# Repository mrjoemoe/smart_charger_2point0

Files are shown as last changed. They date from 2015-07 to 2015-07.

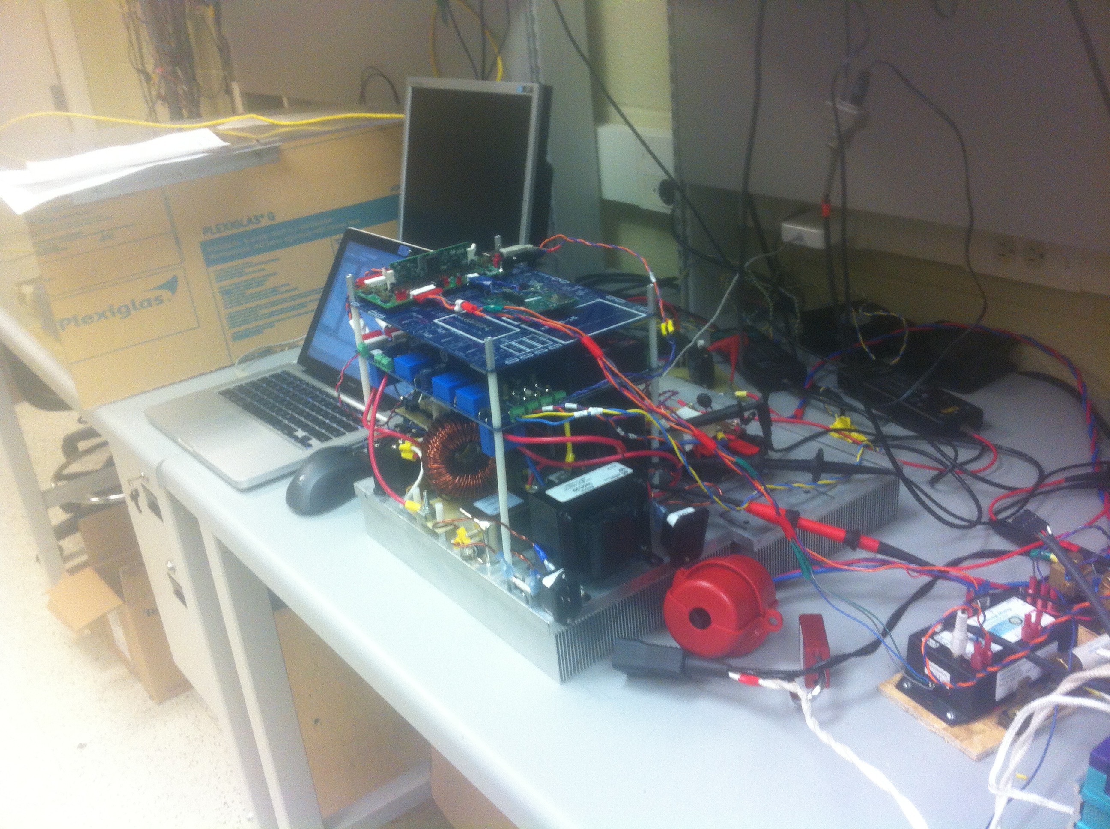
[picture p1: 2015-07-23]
smart_charger_pictures/IMG_2184.JPG

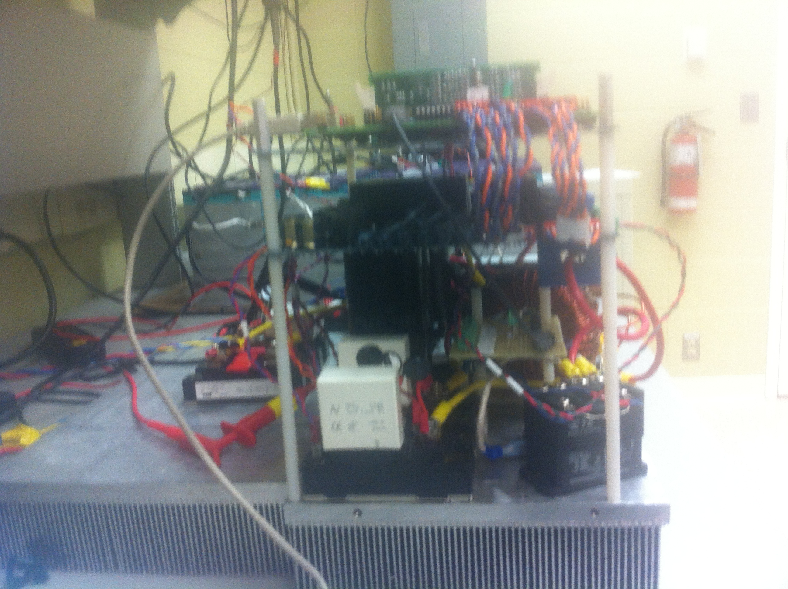
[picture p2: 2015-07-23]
smart_charger_pictures/IMG_2187.JPG

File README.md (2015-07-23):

# smart_charger_2point0
Project folder for the design of a level 1 bidirectional charger

For this project I designed a level 1 bidriectional EV charger capable of charging/discharging a 4kWh battery pack up to 20A @ 120VAC

Uploaded files include:
- firmware for the TMS320F2808 digital signal controller which was written in embedded C
- JS/HTML written for the Muratta SN8200 wifi controller (connected to TMS320F2808 through I2C) for wireless access
- altium files for pcb design
- matlab/simulink files used for controller development and design

My apologies for the poor organization

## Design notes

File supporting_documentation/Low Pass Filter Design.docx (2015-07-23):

Low Pass Filter Design

The digital low pass filter to be implemented in the lab was designed using traditional controller design techniques and state space methods. First a second order low pass filter is designed in the analog domain using traditional techniques. The damping ratio ( ζ) and cutoff frequency ( w_o^2 ) are chosen to be 0.707 and 400π respectively.

G(s)= (w_o^2)/(s^2 +2ζw_o s+ w_o^2)

With these component values chosen it can be seen in Figure 1 that this controller is very stable with both poles far into the open left hand plane and no zeros. However from Figure 2 it can be seen that there is approximately a 53.2O phase lag between the input and output signal and a gain of -0.56 dB. In the lab is it required that the input and output signals are in phase with unity gain. Therefore it is required to design a third order controller.

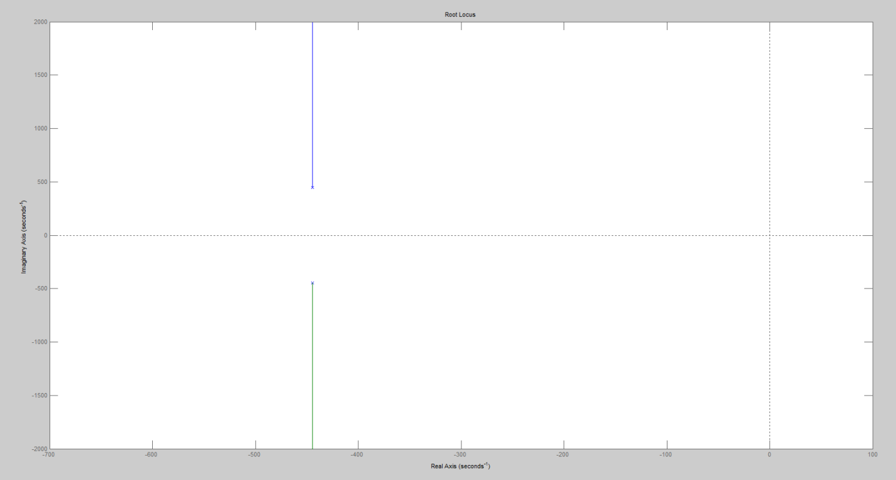
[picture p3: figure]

Figure 1. Low Pass Filter Root Locus Plot (Analog)

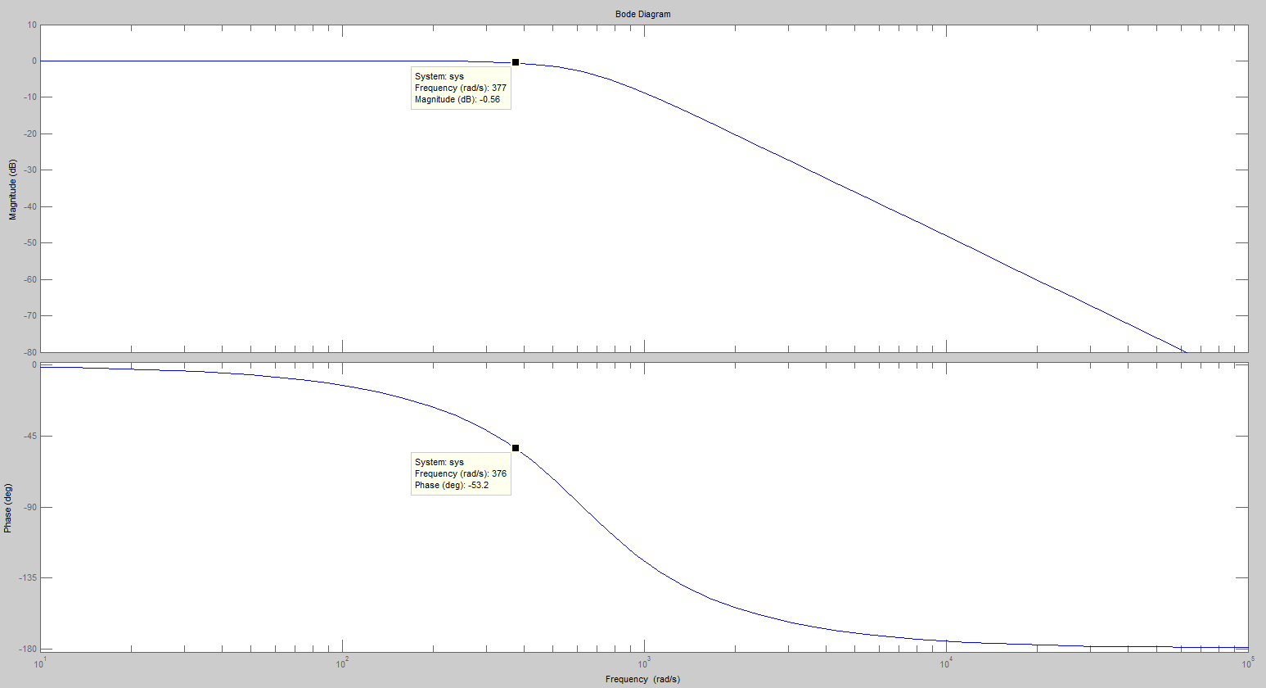
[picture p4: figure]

Figure 2. Low Pass Filter Bode Plot (Analog)

The controller will be augmented to with a lead compensator so that the controller takes on the form

G(s)= K/(√a)((1+aTs)/(1+Ts))((w_o^2)/(s^2 +2ζw_o s+ w_o^2))

where

a= (1+sin∅_m)/(1-sin∅_m)

T= 1/(w_m √a)

The controller will be filtering data at 60 Hz so by setting w_m =120π , ∅_m =53. 2O and selecting K such that unity gain is achieved we get a response as shown in Figure 3 and Figure 4. Now we have a stable low pass filter with a cutoff frequency of 200 Hz that provides unity gain and no phase shift at 60 Hz.

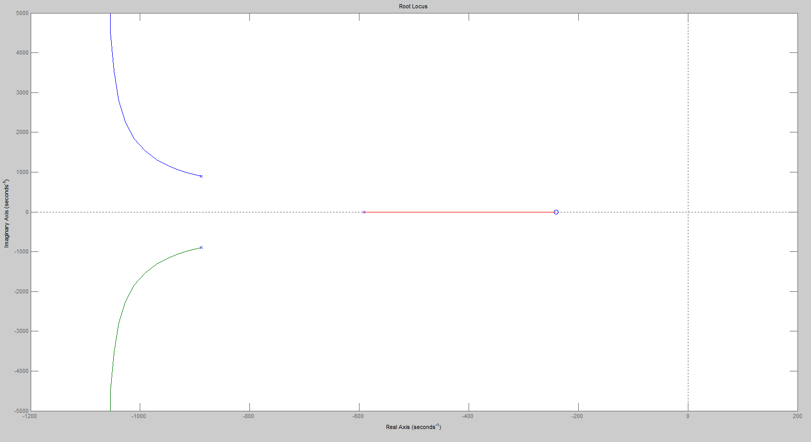
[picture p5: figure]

Figure 3. Third Order Low Pass Filter, root locus, Analog

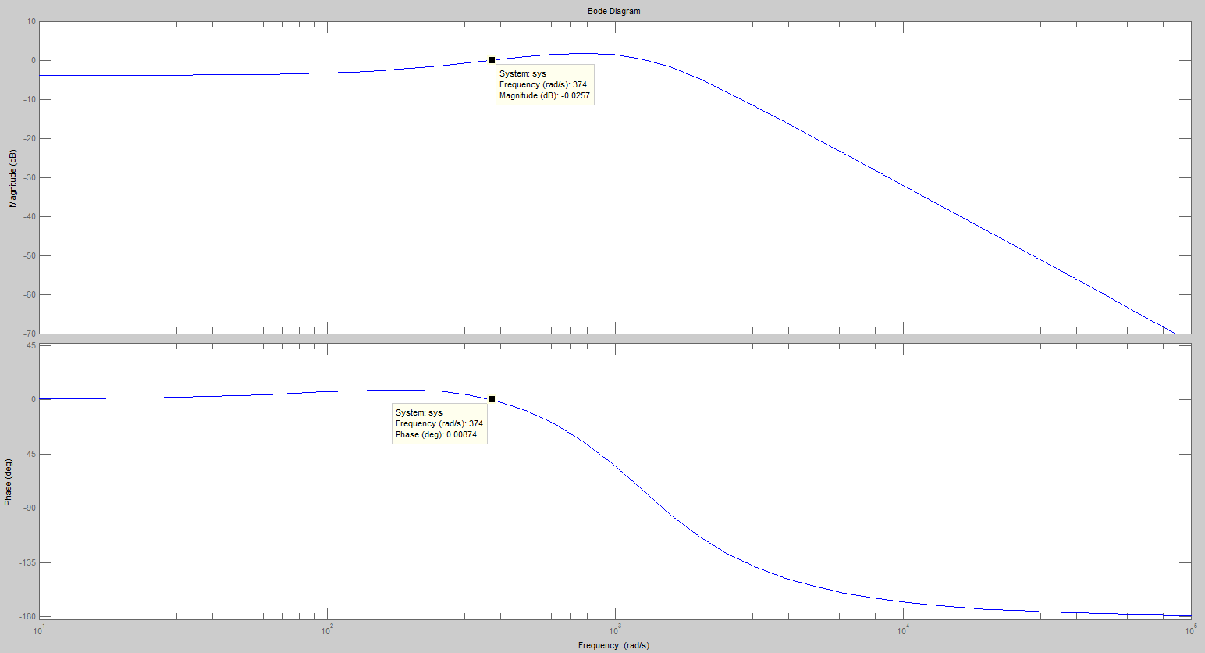
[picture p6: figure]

Figure 4. Third Order Low Pass Filter, bode plot, analog

The next step is to convert the filter to a discrete model that can be implemented with a microcontroller. Using the tools provided in matlab the following script was written to quickly calculate the third order filter parameter values.

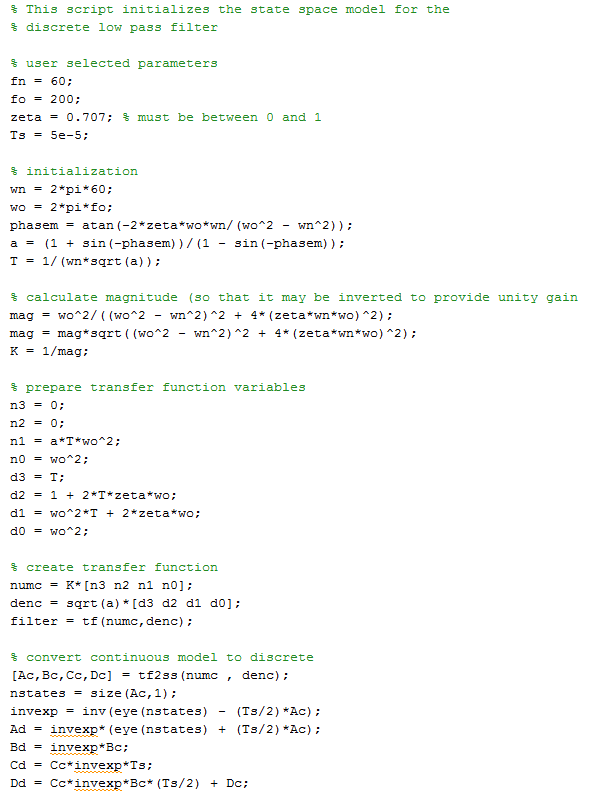
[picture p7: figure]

Once the transfer function is designed it is converted to a state space model using the tf2ss() function. Then the continuous state space model is converted to a discrete state space model using the following conversions:

A_d =(I-(T_s)/2A_c )^(-1) (I+(T_s)/2A_c )

B_d =(I-(T_s)/2A_c )^(-1) B_c

C_d =C_c (I-(T_s)/2A_c )^(-1) T_s

D_d =C_c (I-(T_s)/2A_c )^(-1) B_c ((T_s)/2)+D_c

This results in the following discrete state space parameters:

A_d =[0.8852, -125.0779, -4.4036E-34.7131E-3, 0.9969, -1.10091.1783E-9, 4.9922E-5, 1.0000]

B_d =[0.94262.3566E-55.8914E-10]

C_d =[0.0029, 124.9691, 2.9817E-4]

D_d =[0.0015]

Based on these parameters the output of the filter y[n] can be calculated based on the input u[n] at each sampled period of 50 µs according to the state space relationship below.

x[n+1]=A_d x[n]+ B_d u[n]

y[n]=C_d x[n]+ D_d u[n]

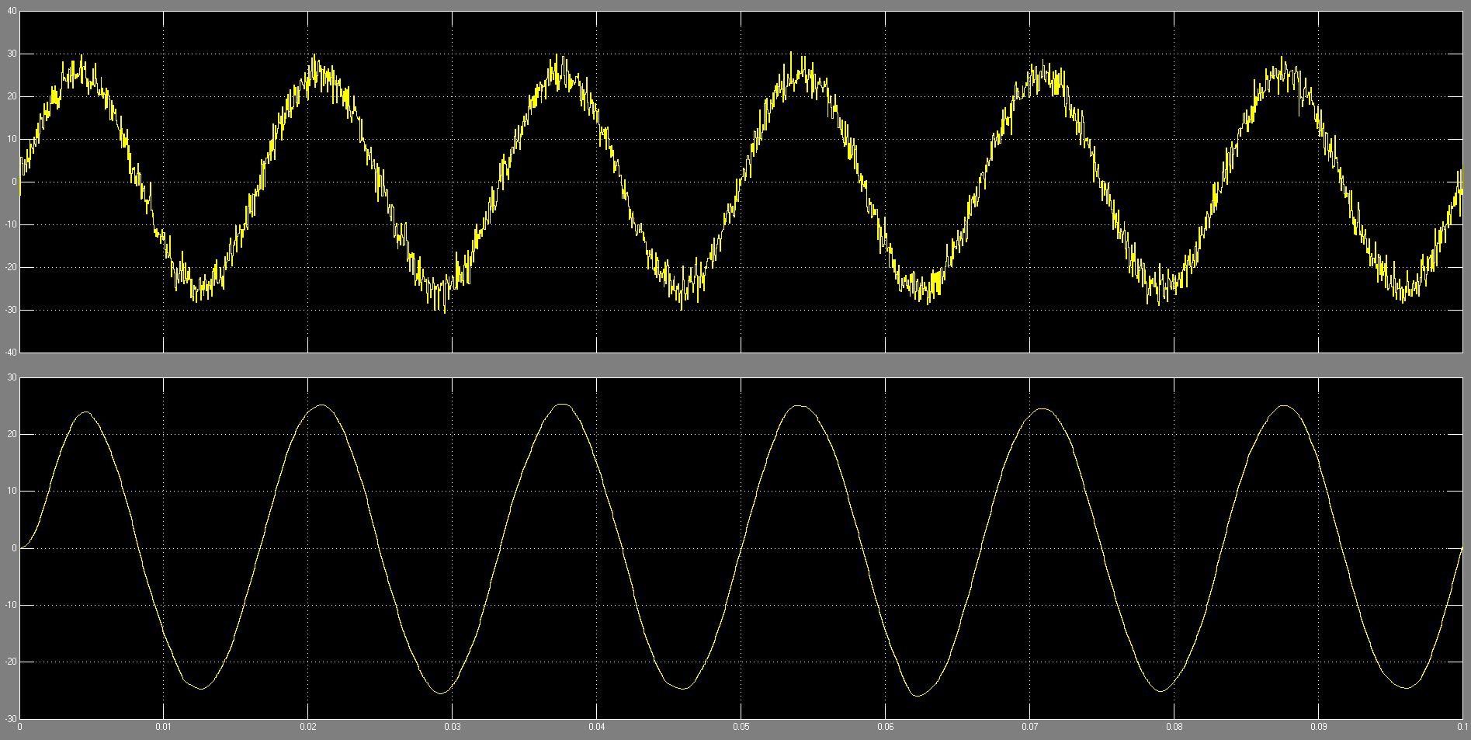
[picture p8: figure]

Figure 5. Sample of Digital Filter

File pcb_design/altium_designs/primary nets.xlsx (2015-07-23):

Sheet: nets
Primary Nets | Desciption
+15V | +15V supply for voltage and current sensors
-15V | -15V supply for voltage and current sensors
GND1 | GND supply for voltage sensors, current sensors and fiber optic transmitters
GND2 | GDN supply for fiber optic receivers
5V1 | 5V supply for opamps in voltage and current sensors
5V2 | 5V supply in fiber optic receivers
15V2 | 15V supply for igbt gate drivers
IGBT1 | igbt 1 emitter voltage
IGBT2 | igbt 2 emitter voltage
IGBT3 | igbt 3 emitter voltage
IGBT4 | igbt 4 emitter voltage
IGBT5 | igbt 5 emitter voltage
IGBT6 | igbt 6 emitter voltage

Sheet: sheet names
sheet | code
gate_drive_array | G
fo_tx_array | T

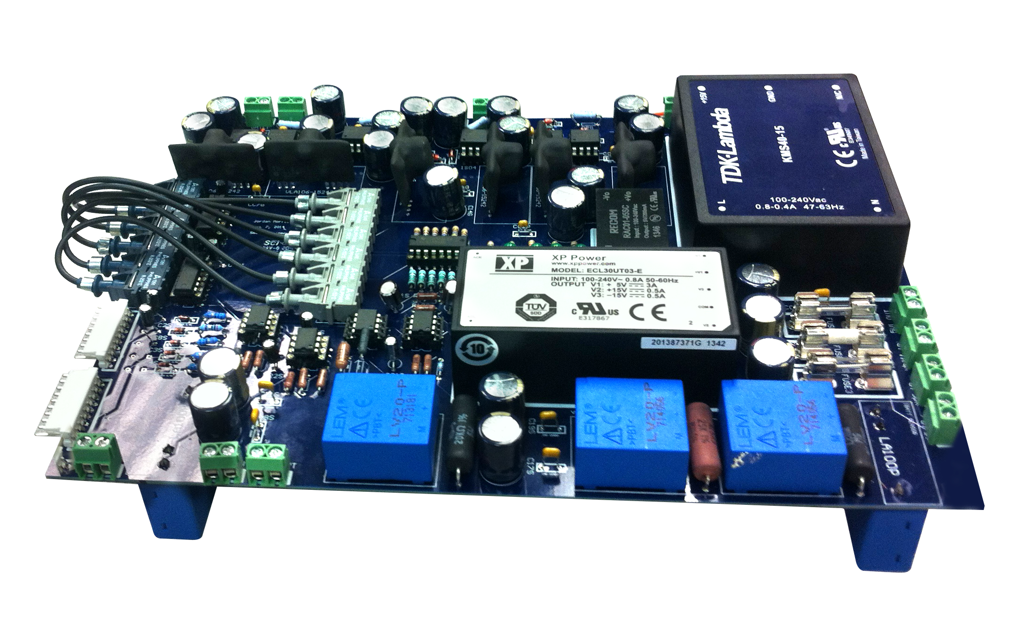
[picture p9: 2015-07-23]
smart_charger_pictures/pcba_final.png

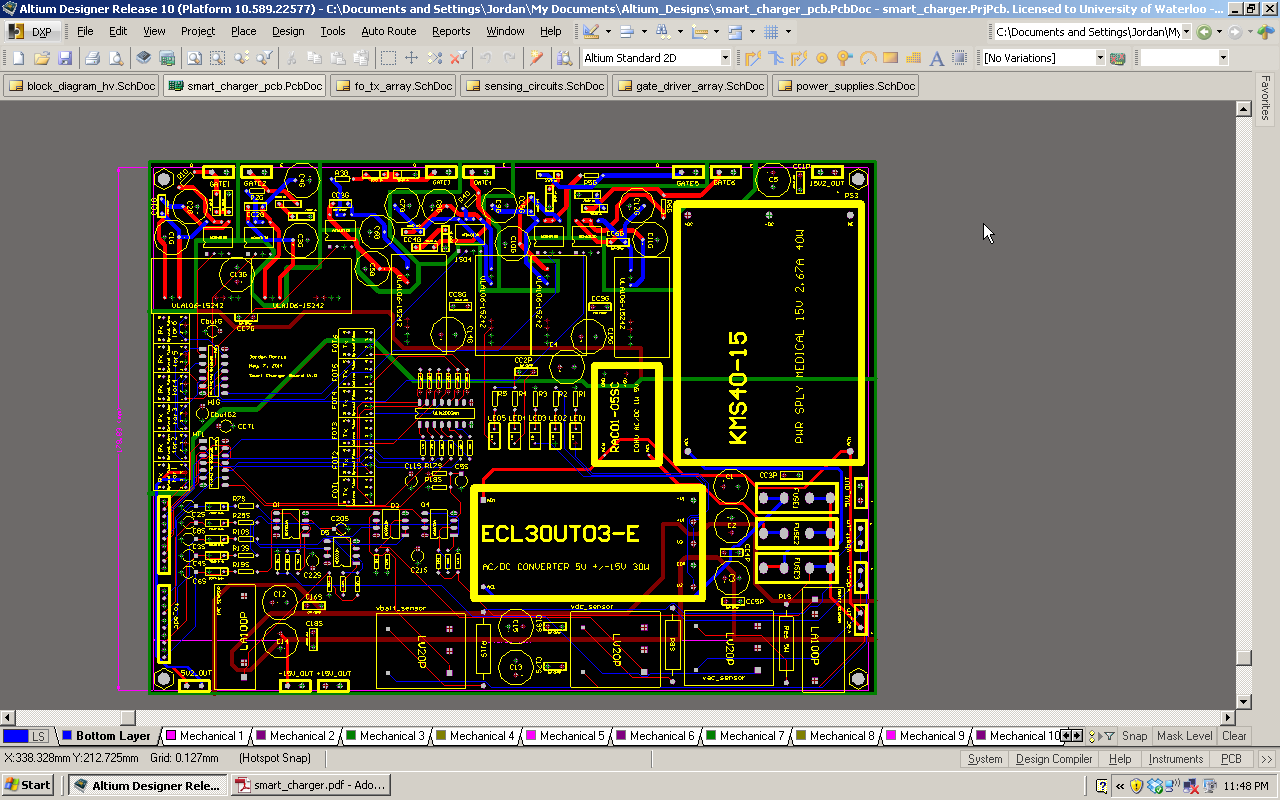
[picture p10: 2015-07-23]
smart_charger_pictures/pcb.bmp

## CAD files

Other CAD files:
tms320f2808_firmware/Debug_RAM/mainxs.obj
tms320f2808_firmware/Debug_RAM/main (Jordans MacBook.lan's conflicted copy 2013-12-22).obj
tms320f2808_firmware/Flash/main.obj
tms320f2808_firmware/Debug_RAM/mainfeedforward.obj
tms320f2808_firmware/Debug_RAM/maindouble.obj
tms320f2808_firmware/Debug_RAM/mainfeedbackzero.obj
tms320f2808_firmware/Debug_RAM/mainopenloop.obj
tms320f2808_firmware/Debug_RAM/main.obj
tms320f2808_firmware/Debug_RAM/mainfeedforward20091221.obj
tms320f2808_firmware/Debug_RAM/mainclosedloop_P_20091208.obj
tms320f2808_firmware/Flash/DSP280x_CodeStartBranch.obj
tms320f2808_firmware/Debug_RAM/DSP280x_CodeStartBranch.obj
tms320f2808_firmware/Flash/INVERTER_control.obj
tms320f2808_firmware/Debug_RAM/overload.obj
tms320f2808_firmware/Debug_RAM/INVERTER_control.obj

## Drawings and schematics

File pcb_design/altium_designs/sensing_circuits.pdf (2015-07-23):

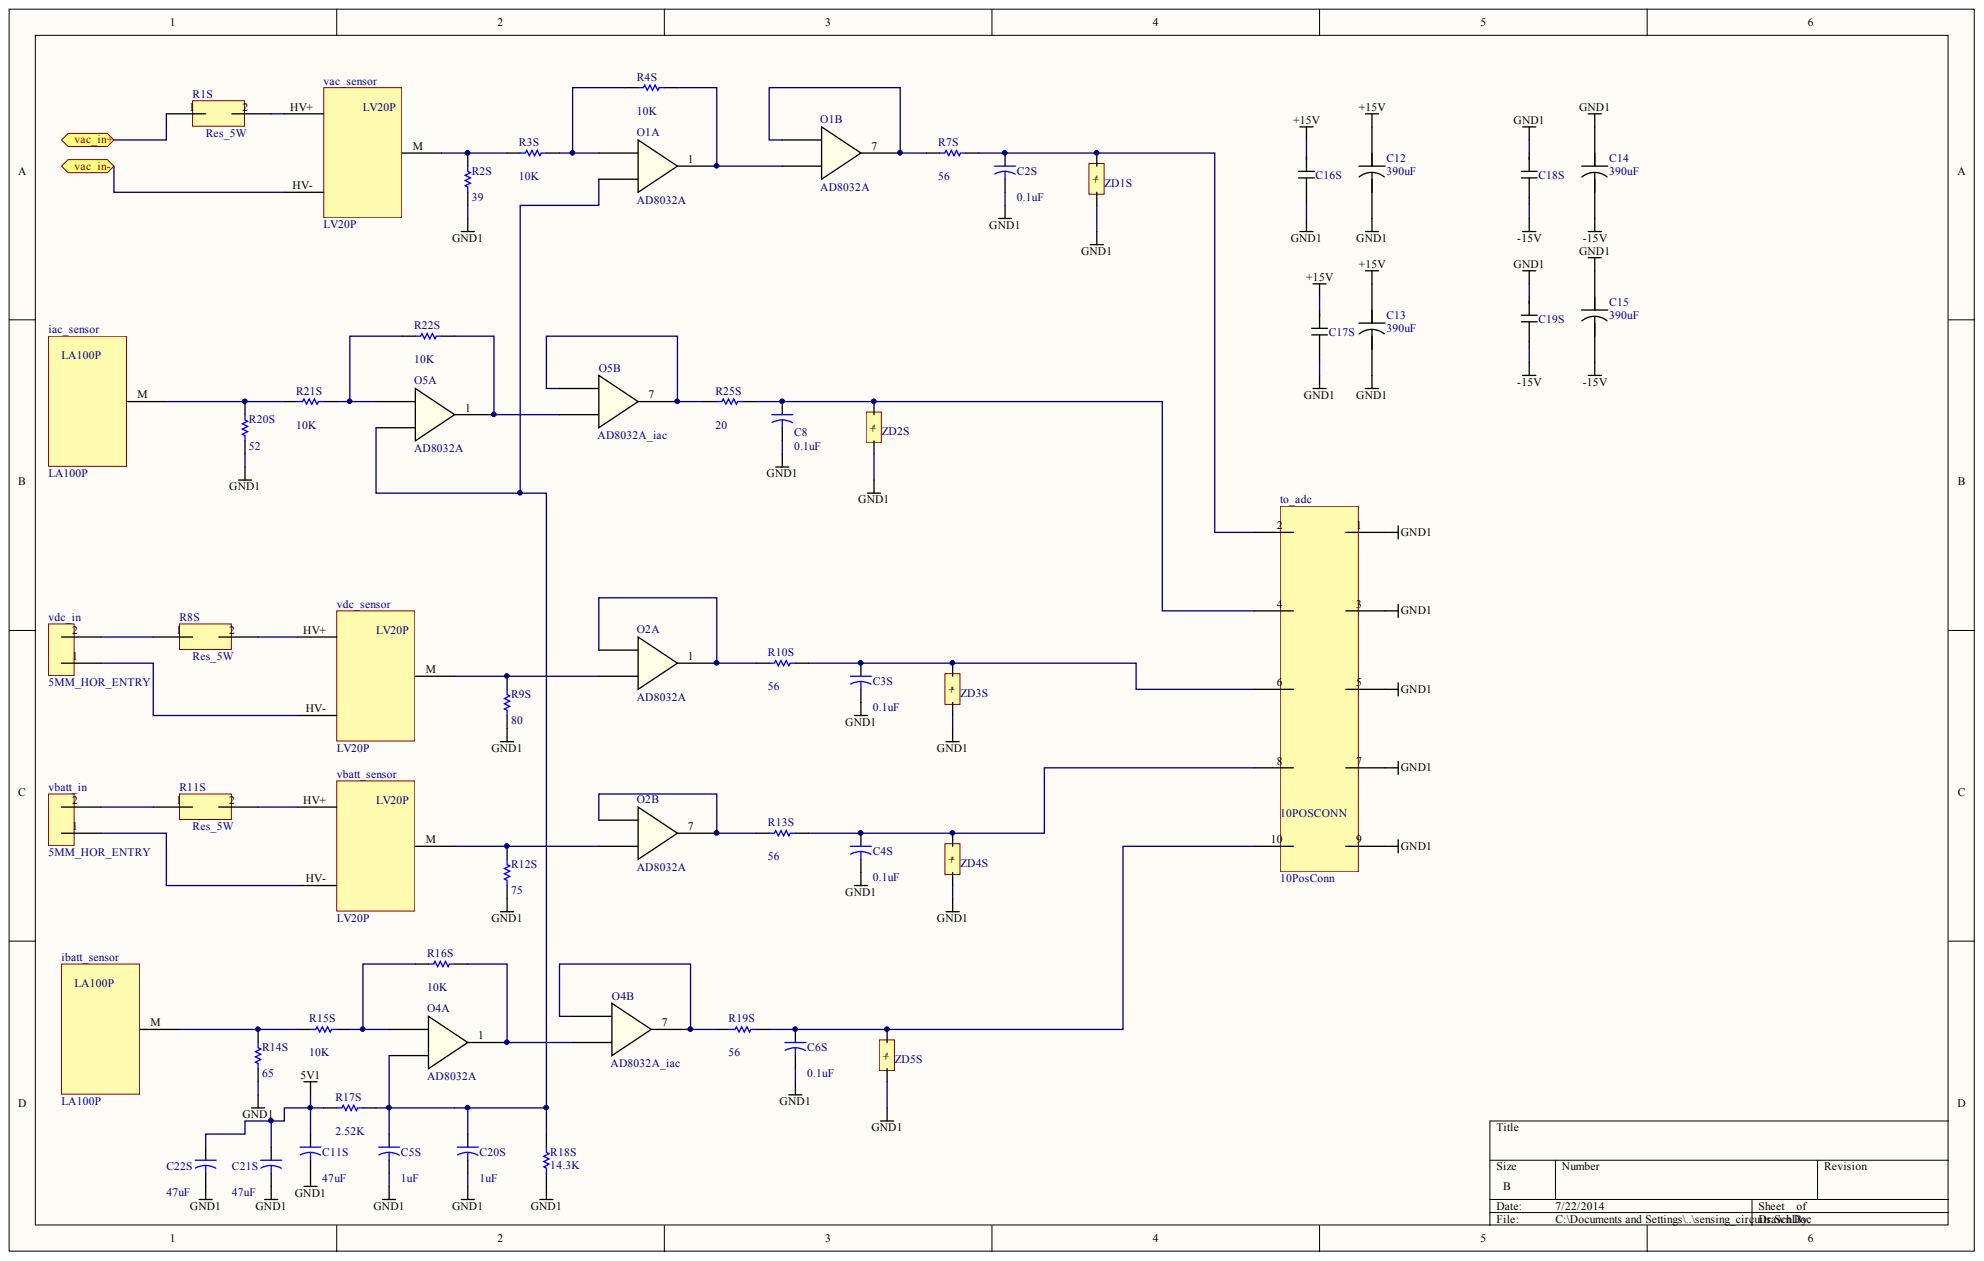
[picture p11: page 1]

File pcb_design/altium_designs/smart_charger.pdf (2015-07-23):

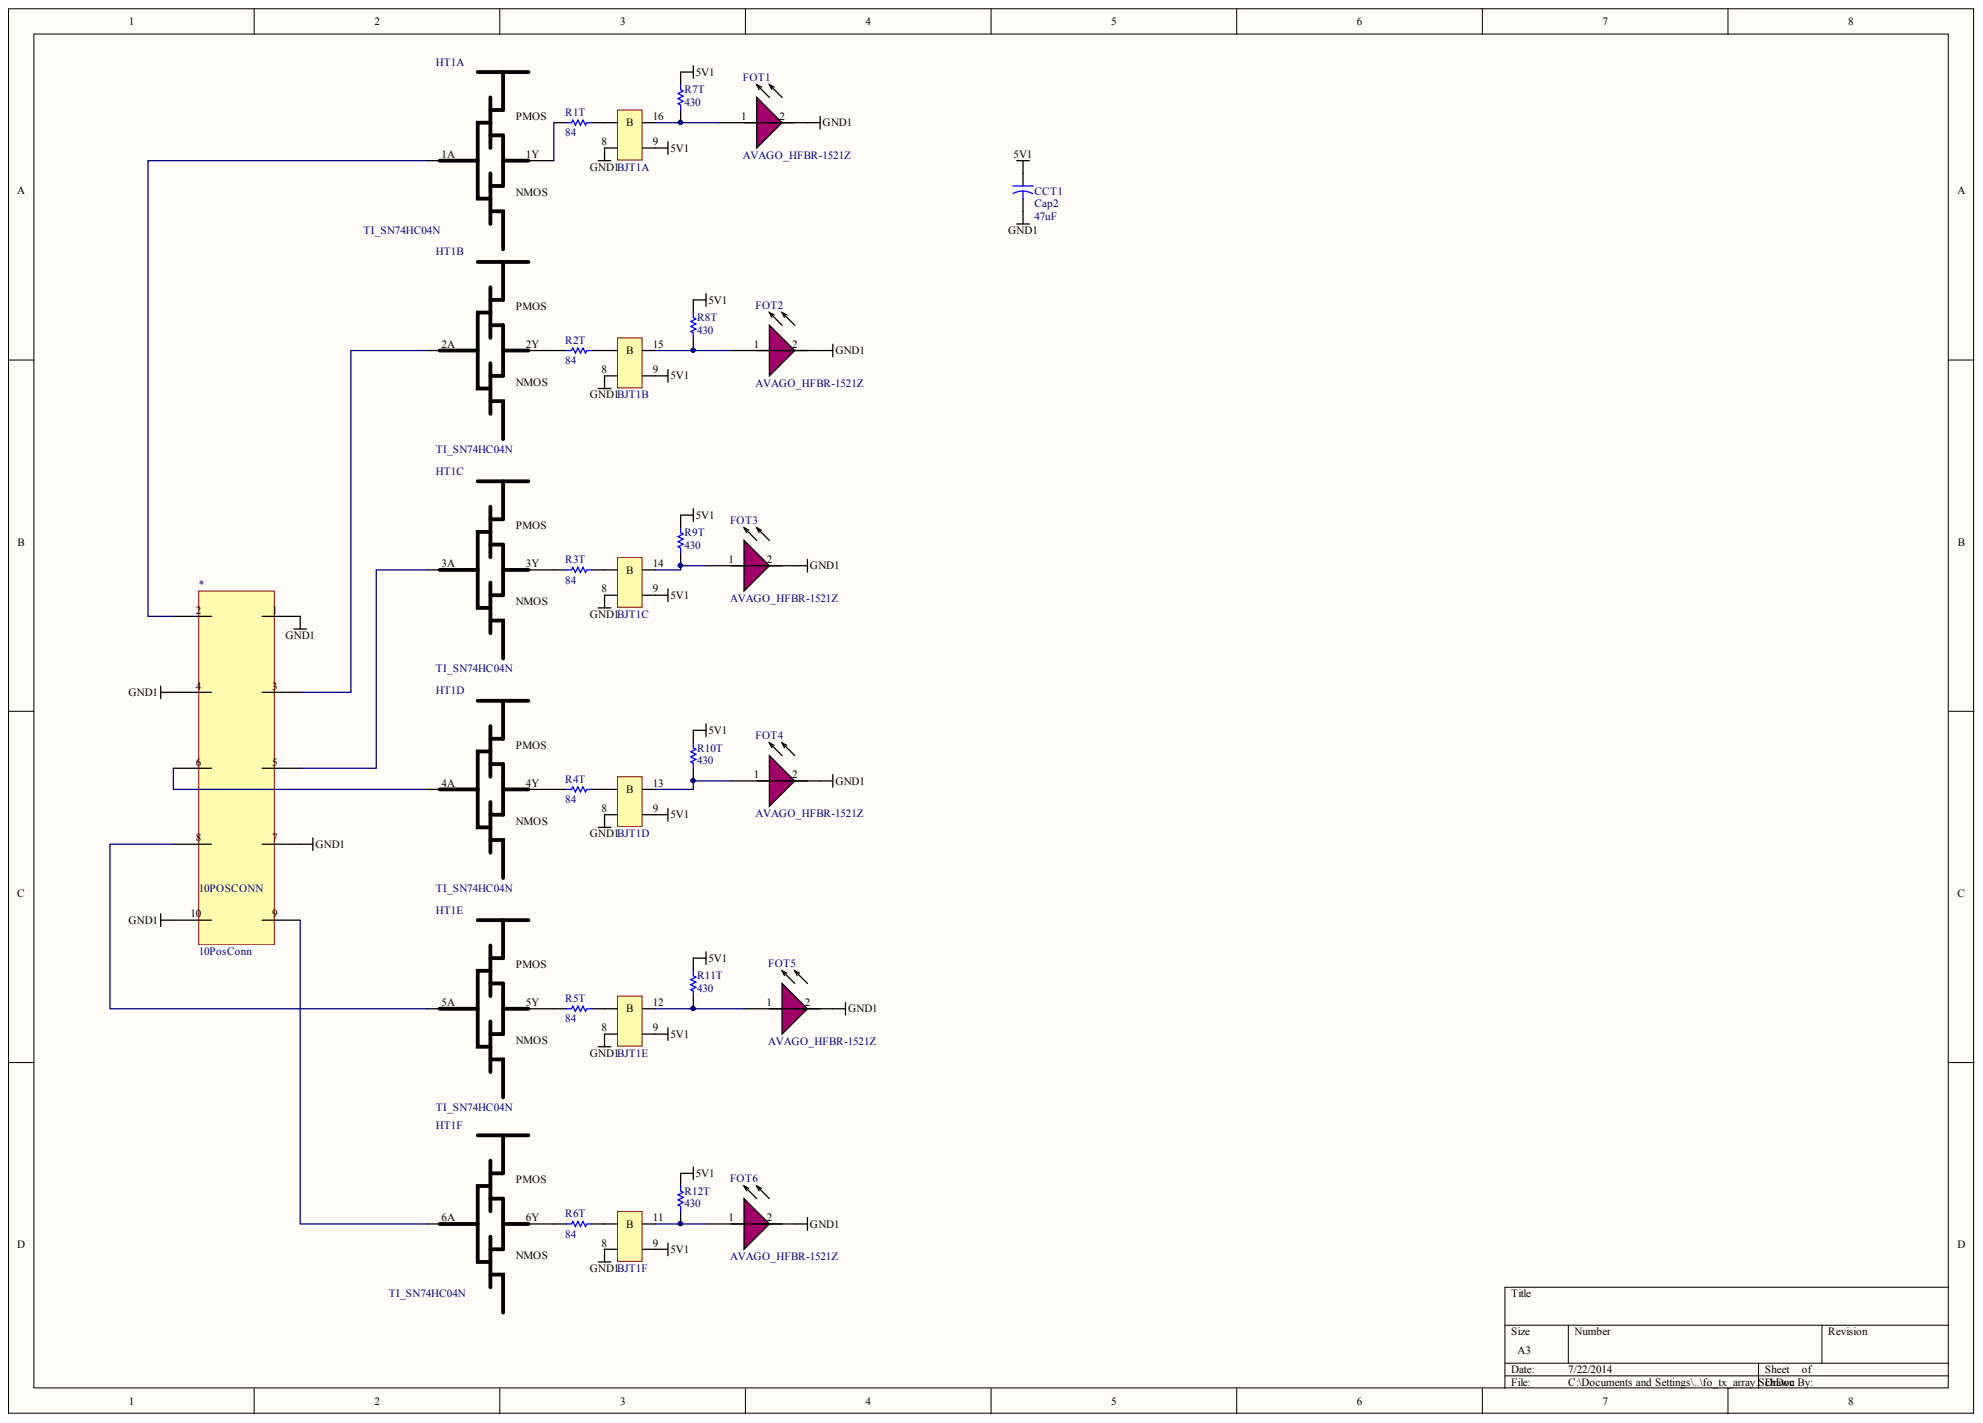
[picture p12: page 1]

10POSCONN | 9

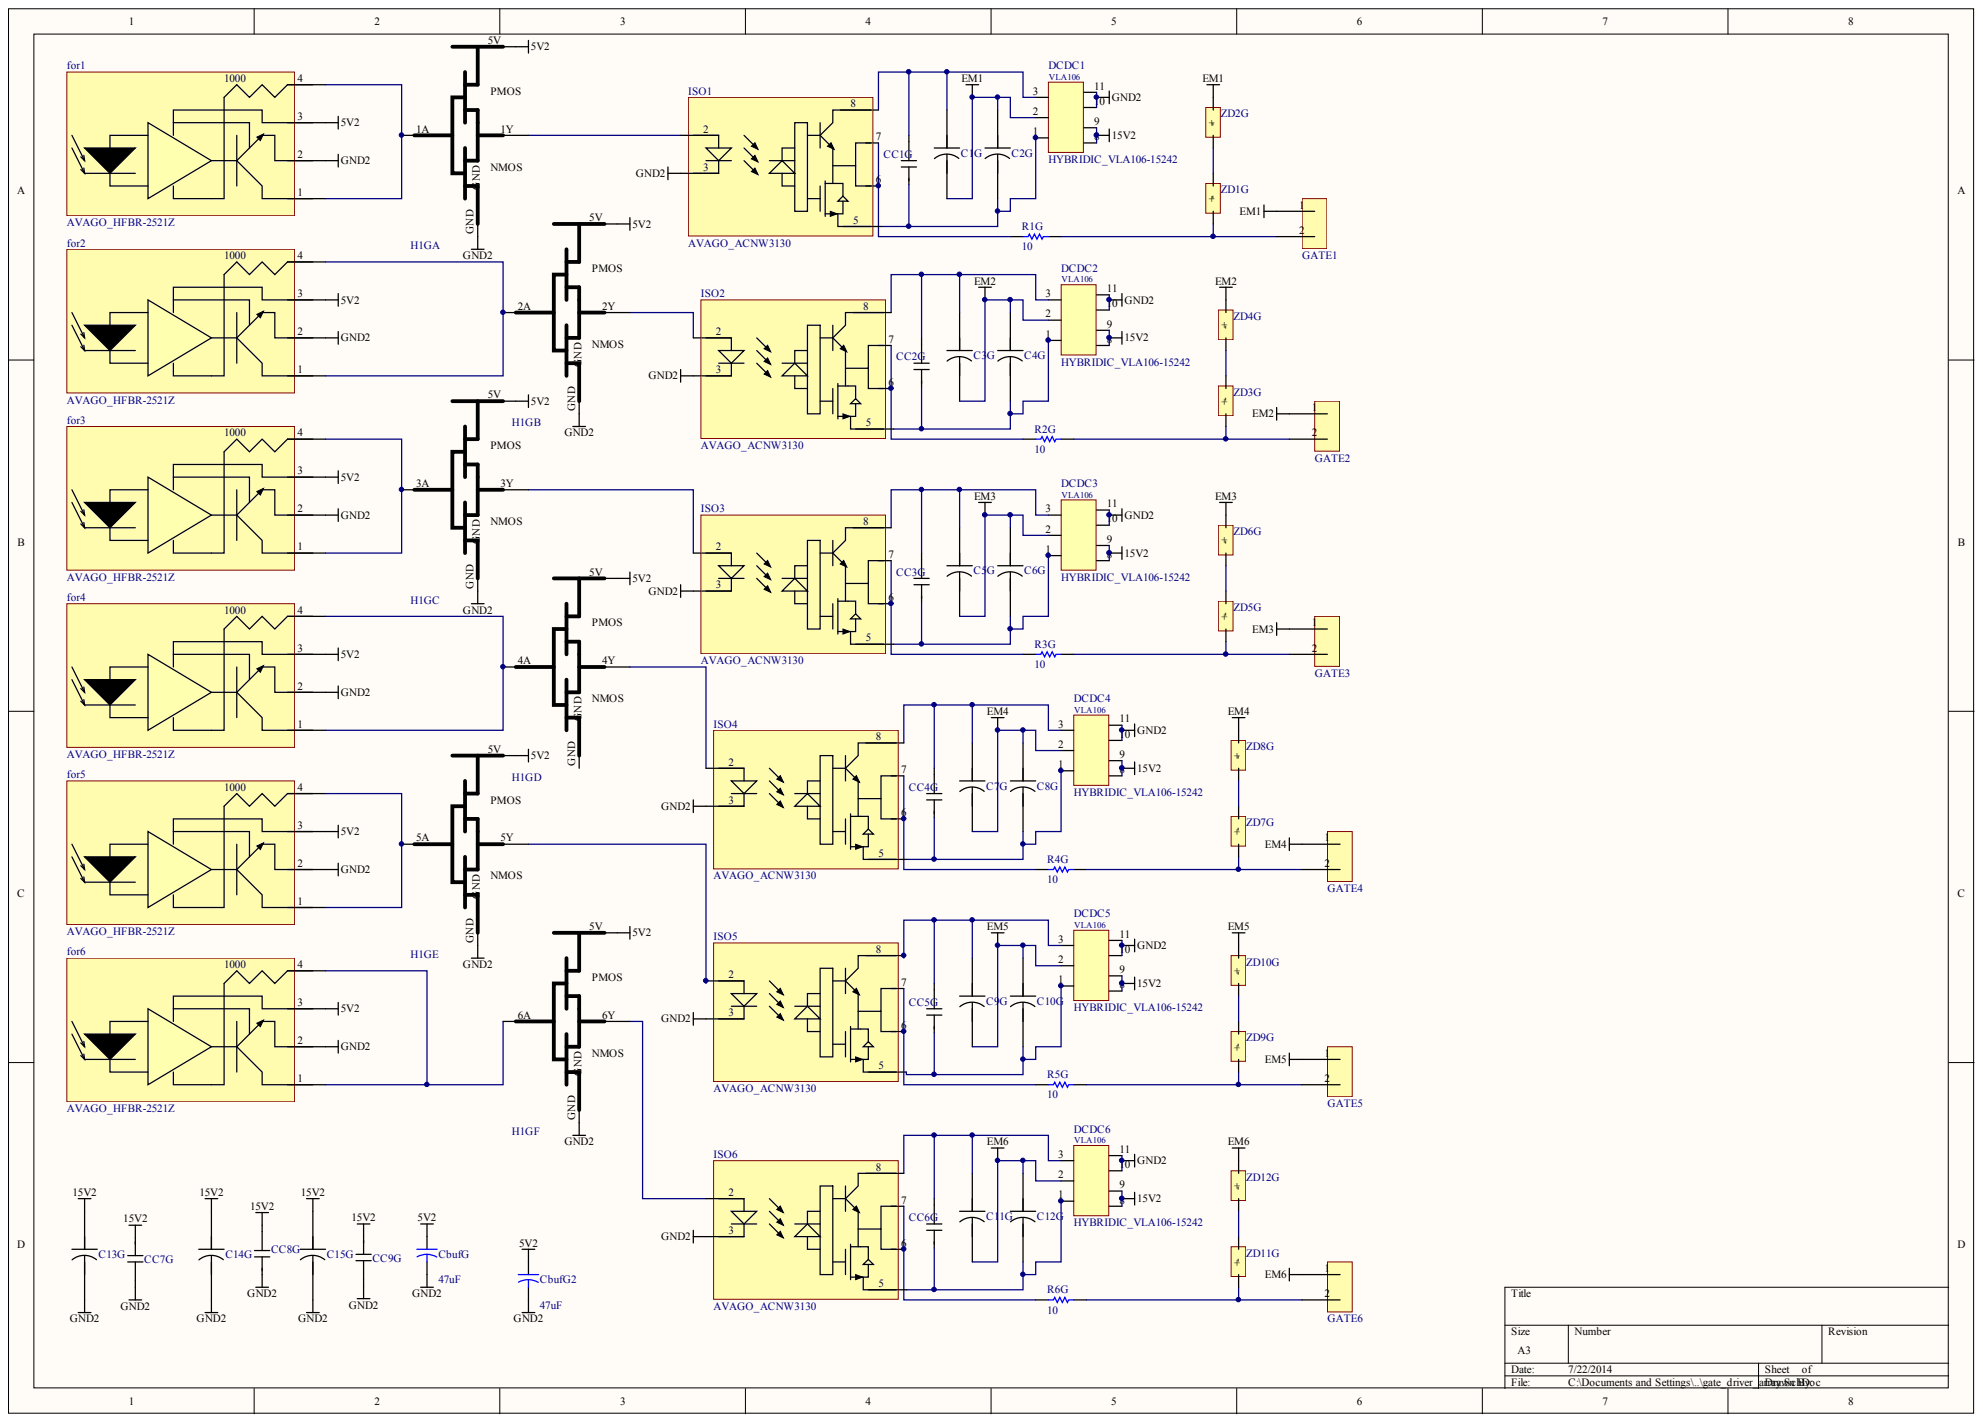
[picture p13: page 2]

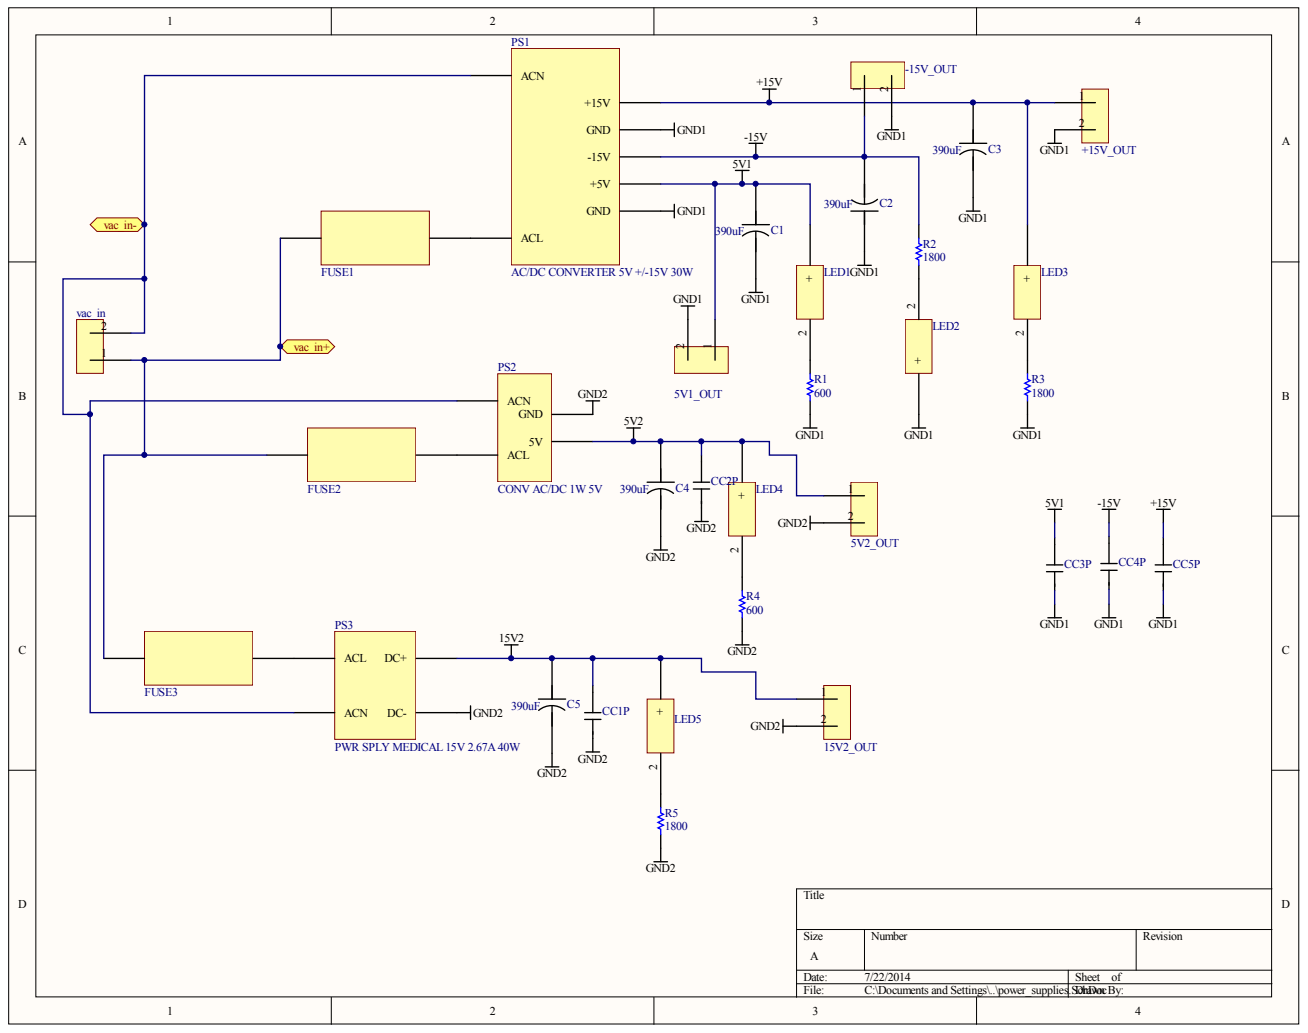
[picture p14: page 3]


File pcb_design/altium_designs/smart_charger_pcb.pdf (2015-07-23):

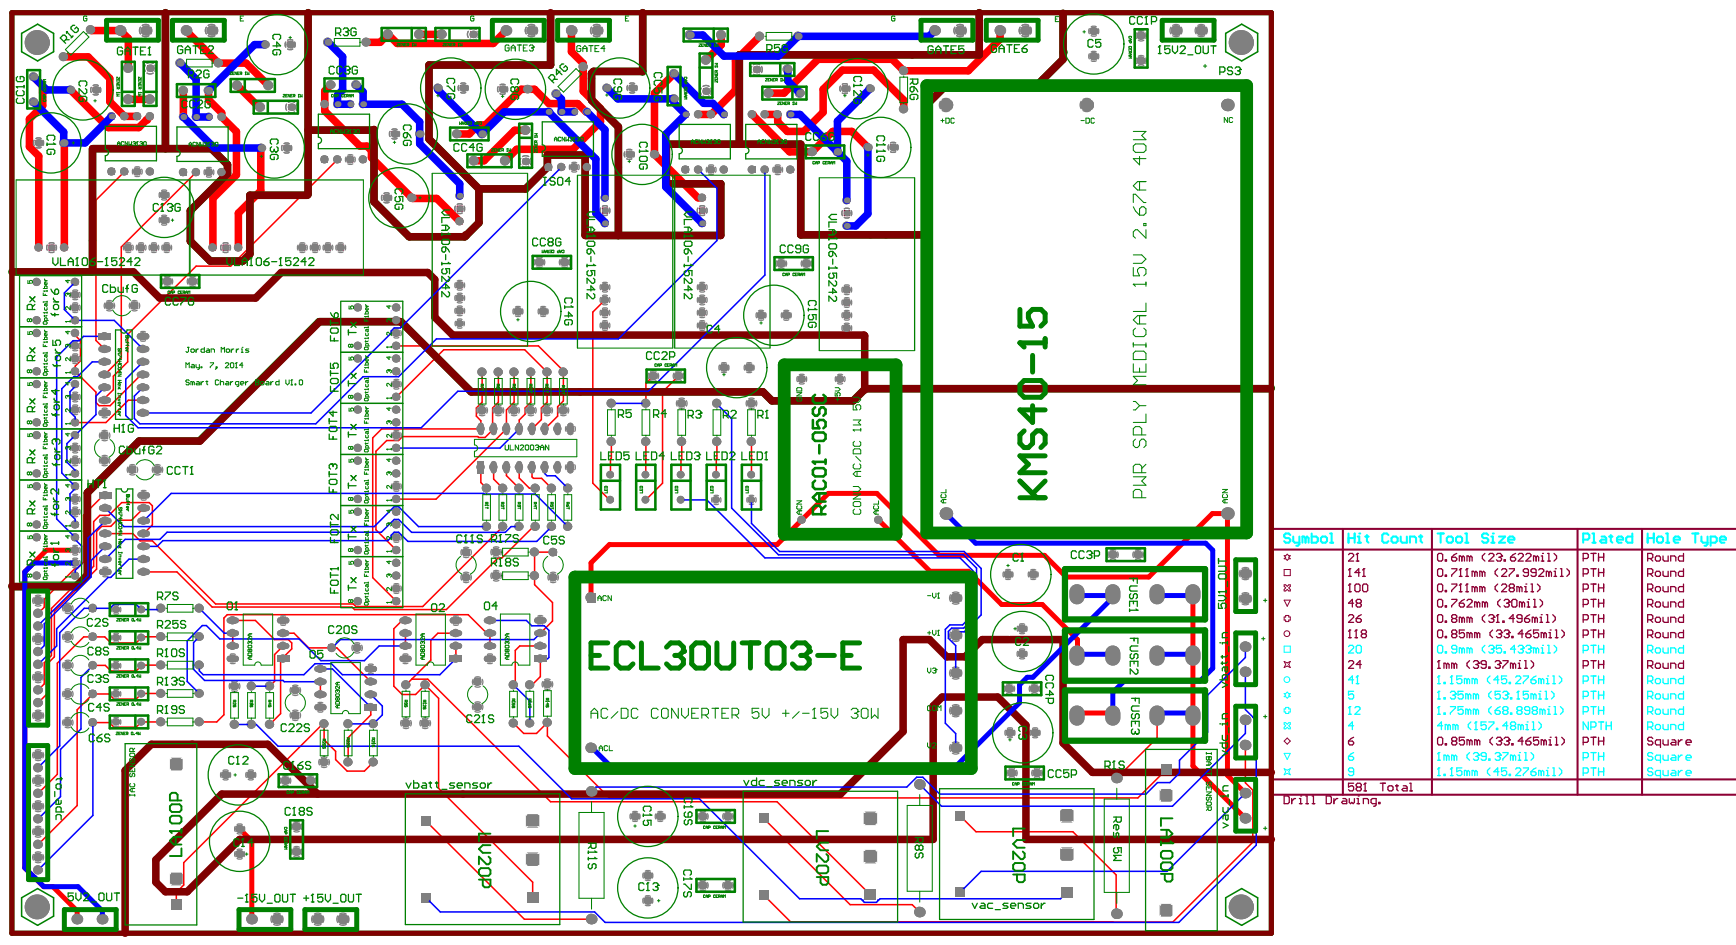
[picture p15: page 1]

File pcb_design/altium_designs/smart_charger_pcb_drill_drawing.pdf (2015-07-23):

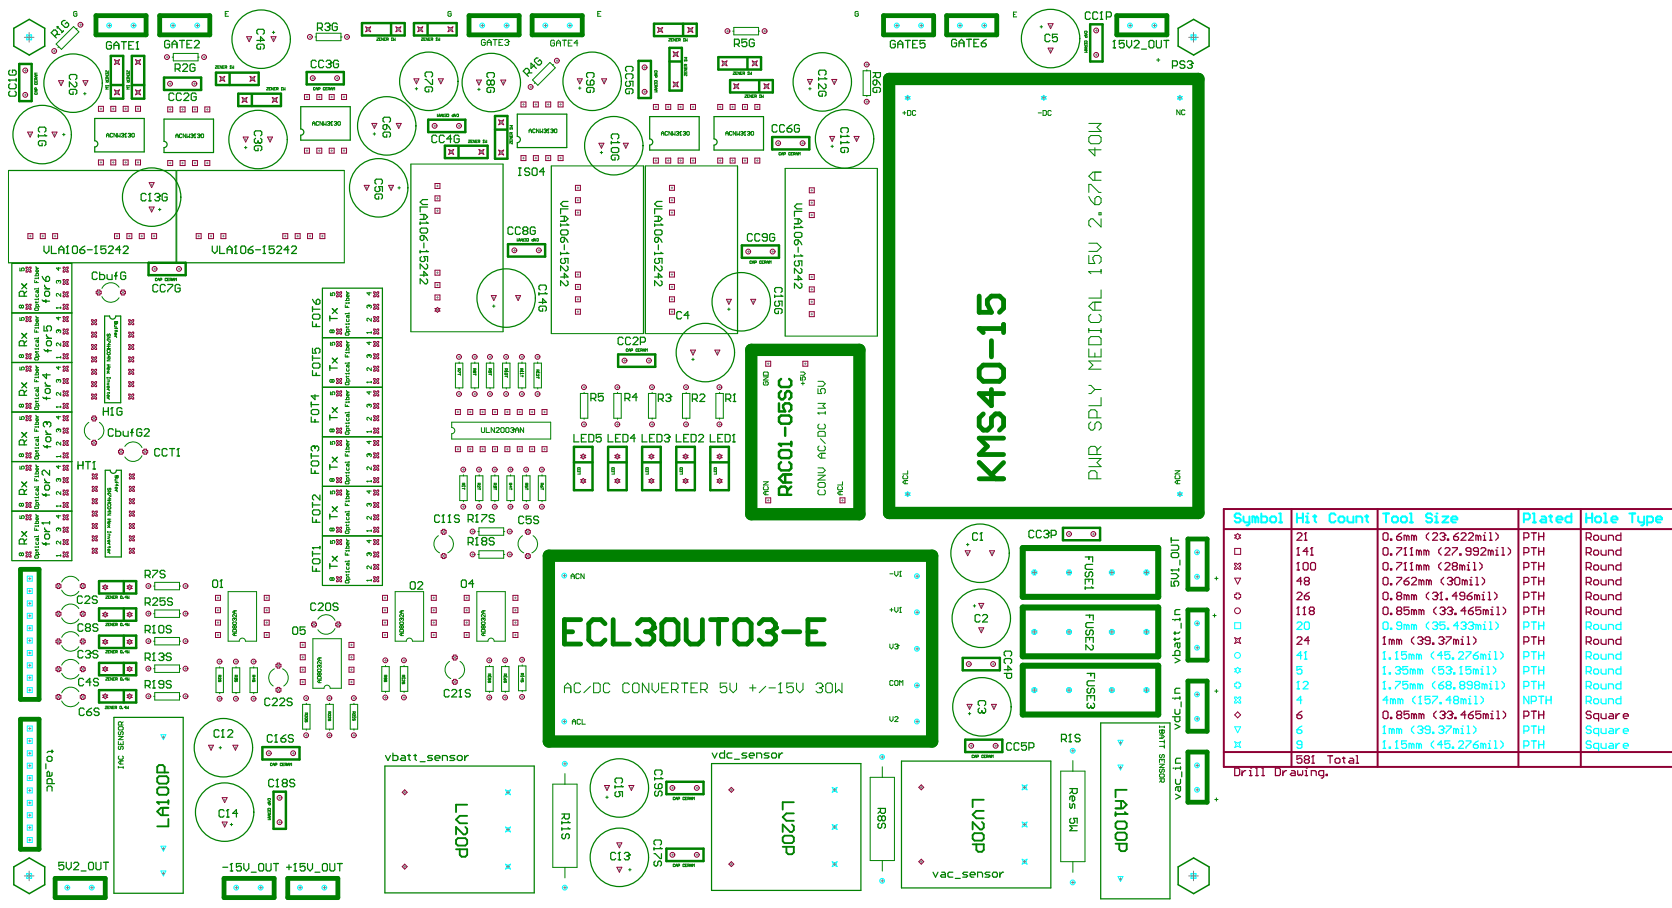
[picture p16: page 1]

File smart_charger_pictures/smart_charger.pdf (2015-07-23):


10POSCONN | 9




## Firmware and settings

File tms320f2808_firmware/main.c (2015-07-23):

// AC/DC Converter
// Jordan Morris
// Nov. 7, 2013

// START

// Table of Contents

//  S0.1 	System Header Files Declarations

//  S1.1 	Function Defintions
//  S1.2 	Main Function
//  S1.2.1 	PLL,WatchDog,Clocks initialization
//  S1.2.2 	PIE initialization
//  S1.2.3 	Set GPIO as EPWM
//	S1.2.4 	Set GPIO as LEDS and switches
//	S1.2.5 	FLASH initialization
//	S1.2.6 	ePWM synchronization
//	S1.2.7 	ePWM initilization
//	S1.2.8 	ADC initialization
//	S1.2.9 	Interrupt Initilization Section

//	S2.0 	Main Control Run
//	S2.1 	PI Controller Algorithm
//	S2.2 	DQ Controller Algorithm
//  S2.3 	enable acdc igbts
//  S2.4 	protection function
//  S2.5 	ADC sampler function
//	S2.6 	ac dc gate driver function
//  S2.7 	RMS calculation
//  S2.8 	digital filter function
//  S2.9 	Proportional-Integral Block
//  S2.10 	Vd Correction Factor 
//  S2.11 	Vq correction Factor
//  S2.12 	Id correction factor
//	S2.13 	Iq correction factor
//	S2.14 	Vab-dq Transform
//  S2.15 	Iab-dq transform
//  S2.16 	Power Calculations
//	S2.17 	AC/DC reverse power flow
//	S2.18 	DC/DC gate drivers
//	S2.19 	Constant Voltage Charging Mode
//	S2.20 	Constant Current Charging Mode
//  S2.21 	Active Power Controller
//  S2.22 	Reactive Power Controller
// 	S2.23 	Mode Select
// 	S2.24 	DC/DC igbts ON
// 	S2.25 	DC/DC igbts OFF
//	S2.26	AC/DC variable reset
// 	S2.27	DC/DC variable reset
//	S2.28	Advanced Calculations
// 	S2.29	Total Harmonic Distortion Calculator
//	S2.30	Total demand distortion calculator
//	S2,31	Error Check
//	S2.32	DC Filter
//  S2,33	Battery Charge Mode
//  S2,34	Battery Discharge Mode 	


//===========================================================================
// S0.1 System Header Files Declarations
#include "dplib280x.h"
#include "dsp280x_compact.h"
#include "math.h"
#include "IQmathLib.h"
#include "variables.h"
//	Global IQ is 19
//---------------------------------------------------------------------------



//S1.1 Function Defintions


// These are system defined functions, needed for interrupt control
void InitSysCtrl(void);
void InitPieCtrl(void); // necessary to use EPWM, see TMS320F2808 Datasheet pg 55
void InitPieVectTable(void);
//---------------------------------------------------------------

// Interrupt
interrupt void control_run(void); // user defined interrupt
//---------------------------------------------------------------


////////////////////// User defined functions //////////////////////// 
void 	ADCsampling(void);		// user defined function
void 	dq_control(_iq nVdcRef , _iq nIqRef);
void 	acdc_gate_drivers(void);
void 	acdc_on(void);
void	acdc_off(void);
_iq		digital_filter(_iq nInput, _iq22 *x1 , _iq30 *x2 , _iq30 *x3);
_iq 	*ab_dq(_iq nAlpha , _iq nBeta , _iq theta);
_iq 	pi_controller(_iq kI , _iq kP , _iq input , _iq *Iold , _iq30 sTime);
_iq 	rms(_iq nInput , _iq *nInteg , _iq nDelayTerm[] , _iq *nCorrDelayTerm);
_iq 	*iab_dq(_iq nA , _iq nB , _iq nTheta , _iq nPhi);
_iq 	*vab_dq(_iq nA , _iq nB , _iq nQ , _iq *nTheta , _iq *pll_int);
_iq 	*power(void);
void 	reverse_power(void);
void 	dcdc_gate_drivers(void);
void 	cv_charging(_iq nRef);
void 	cc_charging(_iq nRef);
void 	cp_charging(_iq nPref);
_iq 	crp_charging(_iq nQref , _iq *reactive_int);
char 	mode_select(void);
void 	dcdc_on(void);
void 	dcdc_off(void);
void	acdc_variable_reset(void);
void	dcdc_variable_reset(void);
void	advanced_calcs(void);
char	overvoltage(void);
char 	overcurrent(void);
_iq		dc_filter(_iq nInput , _iq *x);
char	battery_mode(void);
void	battery_charge(void);
void	battery_discharge(void);
void	power_charge(void);


//S1.2 Main Function 
void main(void)
{

	int	j=0,k=0;


//  S1.2.1 PLL,WatchDog,Clocks initialization
	InitSysCtrl();
	DINT;									//Interrupt Forbiden 


//	S1.2.2 PIE initialization
	InitPieCtrl();							//Initialization of PIE controller memory 
	IER = 0x0000;	
	IFR = 0x0000;                           // Disable CPU interrupts and clear all CPU interrupt flags
	InitPieVectTable();						// Initialization of PIE interrupt lookup table 




//	S1.2.3 Set GPIO as EPWM
	EALLOW; 
    GpioCtrlRegs.GPAMUX1.bit.GPIO0		=0;	   	//sets GPIO0 to EPWM1A if bit is set to 1
	GpioCtrlRegs.GPADIR.bit.GPIO0		=1;	   
	GpioDataRegs.GPACLEAR.bit.GPIO0		=1;   

    GpioCtrlRegs.GPAMUX1.bit.GPIO1		=0;	   	//sets GPIO1 to EPWM1B if bit is set to 1
	GpioCtrlRegs.GPADIR.bit.GPIO1		=1;	   
	GpioDataRegs.GPACLEAR.bit.GPIO1		=1;    

    GpioCtrlRegs.GPAMUX1.bit.GPIO2		=0;	   	//sets GPIO2 to EPWM2A if bit is set to 1
	GpioCtrlRegs.GPADIR.bit.GPIO2		=1;	   
	GpioDataRegs.GPACLEAR.bit.GPIO2		=1;   	

    GpioCtrlRegs.GPAMUX1.bit.GPIO3		=0;	   	//sets GPIO3 to EPWM2B if bit is set to 1
	GpioCtrlRegs.GPADIR.bit.GPIO3		=1;	   
	GpioDataRegs.GPACLEAR.bit.GPIO3		=1;  

    GpioCtrlRegs.GPAMUX1.bit.GPIO4		=0;	   	//sets GPIO4 to EPW3A if bit is set to 1
	GpioCtrlRegs.GPADIR.bit.GPIO4		=1;	   
	GpioDataRegs.GPACLEAR.bit.GPIO4		=1;   	

    GpioCtrlRegs.GPAMUX1.bit.GPIO5		=0;	   	//sets GPIO5 to EPW3B if bit is set to 1
	GpioCtrlRegs.GPADIR.bit.GPIO5		=1;	   
	GpioDataRegs.GPACLEAR.bit.GPIO5		=1; 

	EDIS; 

//	S1.2.4 Set GPIO as LEDS and switches
	EALLOW;
		
	// LED1
	GpioCtrlRegs.GPAMUX2.bit.GPIO26		= 0;
	GpioCtrlRegs.GPADIR.bit.GPIO26		= 1; 
	GpioDataRegs.GPASET.bit.GPIO26		= 1;		

	// LED2
	GpioCtrlRegs.GPAMUX2.bit.GPIO24		= 0;
	GpioCtrlRegs.GPADIR.bit.GPIO24		= 1; 
	GpioDataRegs.GPASET.bit.GPIO24		= 1;	

	// LED3
	GpioCtrlRegs.GPAMUX1.bit.GPIO15		= 0;
	GpioCtrlRegs.GPADIR.bit.GPIO15		= 1; 
	GpioDataRegs.GPASET.bit.GPIO15		= 1;	

	// LED4
	GpioCtrlRegs.GPAMUX1.bit.GPIO12		= 0;
	GpioCtrlRegs.GPADIR.bit.GPIO12		= 1; 
	GpioDataRegs.GPASET.bit.GPIO12		= 1;

	// LED5
	GpioCtrlRegs.GPAMUX2.bit.GPIO29		= 0;
	GpioCtrlRegs.GPADIR.bit.GPIO29		= 1; 
	GpioDataRegs.GPASET.bit.GPIO29		= 1;	

	// LED6
	GpioCtrlRegs.GPAMUX2.bit.GPIO31		= 0;
	GpioCtrlRegs.GPADIR.bit.GPIO31		= 1;
	GpioDataRegs.GPASET.bit.GPIO31 		= 1;	


	// control switches
	// AC/DC ON/OFF Switch
	GpioCtrlRegs.GPAMUX1.bit.GPIO7		= 0; 	// configures as gpio pin
	GpioCtrlRegs.GPADIR.bit.GPIO7		= 0; 	// configures as input
	GpioDataRegs.GPASET.bit.GPIO7		= 0; 	// pin defaults to a low latch
	GpioCtrlRegs.GPAPUD.bit.GPIO7		= 1; 	// disable internal pullup resistors
	GpioCtrlRegs.GPAQSEL1.bit.GPIO7  	= 0x3;

	// DC/DC ON/OFF Switch
	GpioCtrlRegs.GPAMUX1.bit.GPIO9		= 0;
	GpioCtrlRegs.GPADIR.bit.GPIO9		= 0; 
	GpioDataRegs.GPASET.bit.GPIO9		= 0;
	GpioCtrlRegs.GPAPUD.bit.GPIO9		= 1;
	GpioCtrlRegs.GPAQSEL1.bit.GPIO9  	= 0x3;

	// Active Power Control ON/OFF Switch
	GpioCtrlRegs.GPAMUX1.bit.GPIO11		= 0;
	GpioCtrlRegs.GPADIR.bit.GPIO11		= 0; 
	GpioDataRegs.GPASET.bit.GPIO11		= 0;
	GpioCtrlRegs.GPAPUD.bit.GPIO11		= 1;
	GpioCtrlRegs.GPAQSEL1.bit.GPIO11  	= 0x3;

	// Reactive Power Control ON/OFF Switch
	GpioCtrlRegs.GPAMUX1.bit.GPIO13		= 0;
	GpioCtrlRegs.GPADIR.bit.GPIO13		= 0; 
	GpioDataRegs.GPASET.bit.GPIO13		= 0;
	GpioCtrlRegs.GPAPUD.bit.GPIO13		= 1;
	GpioCtrlRegs.GPAQSEL1.bit.GPIO13  	= 0x3;

	EDIS;




//	S1.2.5 FLASH initialization

#ifdef FLASH
// 	Copy time critical code and Flash setup code to RAM
// 	The  RamfuncsLoadStart, RamfuncsLoadEnd, and RamfuncsRunStart
// 	symbols are created by the linker. Refer to the linker files. 
	MemCopy(&RamfuncsLoadStart, &RamfuncsLoadEnd, &RamfuncsRunStart);
// 	Call Flash Initialization to setup flash waitstates
// 	This function must reside in RAM
	InitFlash();	// Call the flash wrapper init function
#endif


//	S1.2.6 ePWM synchronization
	EALLOW;
	SysCtrlRegs.PCLKCR0.bit.TBCLKSYNC = 1;      //synchronize all the EPWMs, Peripheral Clock Control Register 0
	EDIS;


//	S1.2.7 ePWM initilization

	//  EPWM1 Initialization (IGBT1)
	// Time base Submodule initializations
	EPwm1Regs.TBCTL.bit.HSPCLKDIV = TB_DIV1;        // TBCLK=SYSCLKOUT=10ns if 100M
	EPwm1Regs.TBCTL.bit.CLKDIV = TB_DIV1;			
	EPwm1Regs.TBCTL.bit.PRDLD = TB_SHADOW;          // Shadow enabled
	EPwm1Regs.TBPRD = period;                       // T=2*TBPRD*TBCLK=2*2500*10ns=50us=20KHz
	EPwm1Regs.TBPHS.half.TBPHS = 0;                 // phase inactive
    EPwm1Regs.TBCTL.bit.SYNCOSEL =TB_CTR_ZERO;      // EPWM1 is the master bus, all other pwms will sync to 1
    EPwm1Regs.TBCTL.bit.PHSEN = TB_DISABLE;         // No phase difference for EPWM1
	EPwm1Regs.TBCTL.bit.CTRMODE = TB_COUNT_UPDOWN;  // Up and down mode for counter register
   	EPwm1Regs.TBCTR = 0;	

	// Counter Compare Submodule initializations												// set time based register counter to zero
	EPwm1Regs.CMPA.half.CMPA = 0;		    		// Initialize CMPA=0
	EPwm1Regs.CMPB=0;								// Initialize CMPB=0
	EPwm1Regs.CMPCTL.bit.SHDWAMODE=TB_SHADOW;       // CPMA shadow mode	
	EPwm1Regs.CMPCTL.bit.LOADAMODE=CC_CTR_ZERO;		// Load on CTR = zero



	// Action Qualifier Submodule initializations
	EPwm1Regs.AQCTLA.bit.CAU = AQ_SET;				// Output high when CMPA = counter when incrementing 
	EPwm1Regs.AQCTLA.bit.CAD = AQ_CLEAR;			// Output low when CMPA = counter when decrementing


	EPwm1Regs.DBCTL.bit.OUT_MODE = 0x3; 		    // s0=1,s1=1,s2=0,s3=0,s4=0,s5=0
	EPwm1Regs.DBCTL.bit.IN_MODE = 0x0;  			// see pg 52, ePWM reference guide
	EPwm1Regs.DBCTL.bit.POLSEL = 0x2;				// invert b module output       						
	EPwm1Regs.DBRED = db_delay; 				    // 2us rising edge delay
	EPwm1Regs.DBFED = db_delay;						// 2us falling edge delay

	EPwm1Regs.PCCTL.bit.CHPEN = 0;                  // Disable the PWM chopper

	EALLOW;
	EPwm1Regs.TZSEL.bit.OSHT1=1;                    // TZ1 is selected, a one shot trip source
	EPwm1Regs.TZEINT.bit.OST=1;                     // Enable interrupt when a trip event occurs
	EPwm1Regs.TZCTL.bit.TZA=TZ_FORCE_LO;            // Force the EMPW1A to 0 after trip event occurs
	EPwm1Regs.TZCLR.bit.INT=1;                      // Clear the trip-interrupt flag for this EPWM module
	EPwm1Regs.TZCLR.bit.OST=1;                      // Clear flag for one-shot trip latch
	EDIS;

	// EPWM2 Initialization (IGBT2)
	EPwm2Regs.TBCTL.bit.HSPCLKDIV = TB_DIV1;        
	EPwm2Regs.TBCTL.bit.CLKDIV = TB_DIV1;
    EPwm2Regs.TBCTL.bit.PRDLD = TB_SHADOW;          
	EPwm2Regs.TBPRD = period;                       
	EPwm2Regs.TBPHS.half.TBPHS = 0;                 
	EPwm2Regs.TBCTL.bit.SYNCOSEL=TB_SYNC_IN;		// synchonize to epwm1
    EPwm2Regs.TBCTL.bit.PHSEN = TB_DISABLE;         
	EPwm2Regs.TBCTL.bit.CTRMODE = TB_COUNT_UPDOWN;  
	
	EPwm2Regs.CMPA.half.CMPA = 0;		    	
	EPwm2Regs.CMPB=0;								
	EPwm2Regs.CMPCTL.bit.SHDWAMODE=TB_SHADOW;       
	EPwm2Regs.CMPCTL.bit.LOADAMODE=CC_CTR_ZERO;		

	// Action Qualifier Submodule initializations
	EPwm2Regs.AQCTLA.bit.CAU = AQ_SET;				// Output high when CMPA = counter when incrementing 
	EPwm2Regs.AQCTLA.bit.CAD = AQ_CLEAR;			// Output low when CMPA = counter when decrementing


	EPwm2Regs.DBCTL.bit.OUT_MODE = 0x3; 		    // s0=1,s1=1,s2=0,s3=0,s4=0,s5=0
	EPwm2Regs.DBCTL.bit.IN_MODE = 0x0;  			// see pg 52, ePWM reference guide
	EPwm2Regs.DBCTL.bit.POLSEL = 0x2;				// invert b module output       						
	EPwm2Regs.DBRED = db_delay; 				    // 2us rising edge delay
	EPwm2Regs.DBFED = db_delay;						// 2us falling edge delay	
	
	EPwm2Regs.PCCTL.bit.CHPEN = 0;                  // Disable the PWM chopper
	
	EALLOW;
	EPwm2Regs.TZSEL.bit.OSHT1=1;
	EPwm2Regs.TZEINT.bit.OST=1;
	EPwm2Regs.TZCTL.bit.TZA=TZ_FORCE_LO;
	EPwm2Regs.TZCLR.bit.INT=1;
	EPwm2Regs.TZCLR.bit.OST=1;
	EDIS;


	// EPWM3 Initialization (IGBT3)
	EPwm3Regs.TBCTL.bit.HSPCLKDIV = TB_DIV1;        
	EPwm3Regs.TBCTL.bit.CLKDIV = TB_DIV1;
    EPwm3Regs.TBCTL.bit.PRDLD = TB_SHADOW;          
	EPwm3Regs.TBPRD = period;                       
	EPwm3Regs.TBPHS.half.TBPHS = 0;                 
	EPwm3Regs.TBCTL.bit.SYNCOSEL=TB_SYNC_IN;		// synchonize to epwm1
    EPwm3Regs.TBCTL.bit.PHSEN = TB_DISABLE;         
	EPwm3Regs.TBCTL.bit.CTRMODE = TB_COUNT_UPDOWN;  
	
	EPwm3Regs.CMPA.half.CMPA = 0;		    	
	EPwm3Regs.CMPB=0;								
	EPwm3Regs.CMPCTL.bit.SHDWAMODE=TB_SHADOW;       
	EPwm3Regs.CMPCTL.bit.LOADAMODE=CC_CTR_ZERO;		

	// Action Qualifier Submodule initializations
	EPwm3Regs.AQCTLA.bit.CAU = AQ_CLEAR;				// Output high when CMPA = counter when incrementing 
	EPwm3Regs.AQCTLA.bit.CAD = AQ_SET;					// Output low when CMPA = counter when decrementing


	EPwm3Regs.DBCTL.bit.OUT_MODE = 0x3; 		    // s0=1,s1=1,s2=0,s3=0,s4=0,s5=0
	EPwm3Regs.DBCTL.bit.IN_MODE = 0x0;  			// see pg 52, ePWM reference guide
	EPwm3Regs.DBCTL.bit.POLSEL = 0x2;				// invert b module output       						
	EPwm3Regs.DBRED = db_delay; 				    // 2us rising edge delay
	EPwm3Regs.DBFED = db_delay;						// 2us falling edge delay						    // 2us rising edge delay, no falling edge delay	
	
	EPwm3Regs.PCCTL.bit.CHPEN = 0;                  // Disable the PWM chopper
	
	EALLOW;
	EPwm3Regs.TZSEL.bit.OSHT1=1;
	EPwm3Regs.TZEINT.bit.OST=1;
	EPwm3Regs.TZCTL.bit.TZA=TZ_FORCE_LO;
	EPwm3Regs.TZCLR.bit.INT=1;
	EPwm3Regs.TZCLR.bit.OST=1;
	EDIS;      	
	                                                         

//	S1.2.8 ADC initialization
		AdcRegs.ADCTRL3.bit.ADCBGRFDN = 0x3;	    // Power up bandgap/reference circuitry
		for(j=0;j<500;j++)                          // Delay before powering up rest of ADC,5ms
		{
	      for(k=0;k<1000;k++)
		  {		
			asm(" nop");
		  }
		}
		AdcRegs.ADCTRL3.bit.ADCPWDN = 1;		    	// Power up rest of ADC
		for(j=0;j<2000;j++)                         	// Delay after powering up ADC
		{
		  asm(" nop");
		}

		AdcRegs.ADCMAXCONV.all=15;						// 16 sampling channels
		AdcRegs.ADCCHSELSEQ1.bit.CONV00=0x1;			// AC Voltage
		AdcRegs.ADCCHSELSEQ1.bit.CONV01=0x1;
		AdcRegs.ADCCHSELSEQ1.bit.CONV02=0x1;
		AdcRegs.ADCCHSELSEQ1.bit.CONV03=0x2;			// DC Link Voltage
        AdcRegs.ADCCHSELSEQ2.bit.CONV04=0x2;            
        AdcRegs.ADCCHSELSEQ2.bit.CONV05=0x2;
		AdcRegs.ADCCHSELSEQ2.bit.CONV06=0x3;            // AC Current
		AdcRegs.ADCCHSELSEQ2.bit.CONV07=0x3;
		AdcRegs.ADCCHSELSEQ3.bit.CONV08=0x3;            
		AdcRegs.ADCCHSELSEQ3.bit.CONV09=0x3;			
		AdcRegs.ADCCHSELSEQ3.bit.CONV10=0x4;			// Battery Voltage
		AdcRegs.ADCCHSELSEQ3.bit.CONV11=0x4;
		AdcRegs.ADCCHSELSEQ4.bit.CONV12=0x4;			
		AdcRegs.ADCCHSELSEQ4.bit.CONV13=0x5;			// Battery Current
		AdcRegs.ADCCHSELSEQ4.bit.CONV14=0x5;
		AdcRegs.ADCCHSELSEQ4.bit.CONV15=0x5;

		AdcRegs.ADCTRL1.bit.CPS=0;	          //Core clock prescaler. The prescaler is applied to divided device peripheral clock				
		AdcRegs.ADCTRL3.bit.ADCCLKPS=1;	  	  // divide peripheral clock by 2			
		AdcRegs.ADCTRL1.bit.SEQ_CASC=1;				
		AdcRegs.ADCTRL3.bit.SMODE_SEL=0;      // sequential sampling mode selected      
		AdcRegs.ADCTRL1.bit.CONT_RUN = 1;	  // continuous conversion mode      
		AdcRegs.ADCTRL1.bit.ACQ_PS=5;		  // make a large aquisition window size	    
		AdcRegs.ADCTRL2.bit.RST_SEQ1 = 1;	  //		
		AdcRegs.ADCTRL2.bit.SOC_SEQ1 = 1;														
		AdcRegs.ADCTRL2.bit.EPWM_SOCA_SEQ1=1;		





        EPwm6Regs.TBCTL.bit.HSPCLKDIV = TB_DIV1;		// EPWM6 as the base clock for ADC
		EPwm6Regs.TBCTL.bit.CLKDIV = TB_DIV1;
		EPwm6Regs.TBCTL.bit.PRDLD = TB_SHADOW;			// set Immediate load
		EPwm6Regs.TBPRD = period;						// PWM frequency = 1 / period
		EPwm6Regs.TBPHS.all = 0;
		EPwm6Regs.TBCTL.bit.SYNCOSEL = TB_SYNC_DISABLE;

		EPwm6Regs.TBCTR = 0;
		EPwm6Regs.TBCTL.bit.CTRMODE = TB_COUNT_UPDOWN;
		EPwm6Regs.TBCTL.bit.PHSEN = TB_DISABLE;		
		EPwm6Regs.ETSEL.bit.SOCAEN  =  1;
		EPwm6Regs.ETSEL.bit.SOCASEL =  ET_CTRU_CMPA;	// Use CAU event as trigger 
		EPwm6Regs.CMPA.half.CMPA    = 1250;
		EPwm6Regs.CMPB    =  0;
		EPwm6Regs.CMPCTL.bit.SHDWAMODE=TB_SHADOW;       //采用影子寄存器	
	    EPwm6Regs.CMPCTL.bit.LOADAMODE=CC_CTR_ZERO;		//在CTR=PRD时装载

		// Event trigger submodule initialization
        EPwm6Regs.ETPS.bit.SOCAPRD  = 1;        		// Generate pulse on 1st event 
	    EPwm6Regs.ETSEL.bit.SOCAEN  =  1;				// enable pulse on generated event
	    EPwm6Regs.ETSEL.bit.SOCASEL =  ET_CTRU_CMPA;	// Use CAU event as trigger when increasing, ET_CTRU_CMPA = 0x4




//	S1.2.9 Interrupt Initilization Section

//%%%%%%%%%%%%%%%%%%%%%%%%%%%%%%%%%%%%%%%%%%%%%%%%%%%%%%%%%%%%%%%%%%%%%%%%%%%
// Interrupt Init section - System Level and Peripheral Level
// (best to run this section last, once all other initialization is done)
// Note: Make sure same selection is made in PWM-Eval-ISR.ASM
//===========================================================================
	IER |= (M_INT2 | M_INT3);                          // Enable CPU INT3 connected to EPWM1-6 INTs:
//---------------------------------------------------------------------
	EALLOW;
	PieVectTable.EPWM1_INT = &control_run;	           // Map Interrupt to control_run
	EDIS;

    PieCtrlRegs.PIEIER3.bit.INTx1 = 1;	               // EPWM1 INT
	PieCtrlRegs.PIEIER2.bit.INTx1 = 1;                 // EPWM1 TZINT

// EPWM1 level event trigger submodule commands
// ET_CTRU_CMPB=0x6
	EPwm1Regs.ETSEL.bit.INTSEL = ET_CTRU_CMPB;	       // interrupt when TBCTR = CMPB and TBCTR is increasing
	EPwm1Regs.ETSEL.bit.INTEN = TB_ENABLE;			   // Enable INT
	EPwm1Regs.ETPS.bit.INTPRD = ET_1ST;	               // Generate INT on every event


//---------------------------------------------------------------------
// Enable global Interrupts and higher priority real-time debug events:
	EINT;   // Enable Global interrupt INTM
	ERTM;   // Enable Global realtime interrupt DBGM


	dq_ramp = _IQmpy(dq_vdc_ref,_IQ(0.5)) + 20;
	cc_ramp = _IQ(0);
	ADCsampling();
	oc_voltage = vbatt_meas;

//---------------------------------------------------------------
//	mainloop 
//---------------------------------------------------------------  
	for(;;)
	{
		asm("  NOP"); // this is a line of inline assembly
	}

}	






//	S2.0 Main Control Run
interrupt void control_run(void)
{

	current_mode = 0;
	for (i=0 ; i < 10 ; i++)
	{
		mode[i] = mode_select();
		current_mode += mode[i];
	}

	if ((mode[0] * 10) == current_mode)
	{
		prev_mode = mode[0];	
	}

	if	(overvoltage() == 1){prev_mode = 0x00;}
	if	(fault_count > 10) 
	{
		prev_mode = 0x00;
		LED5ON = 1;
	}


	switch(prev_state | prev_mode)
	{
		// AC/DC turn on
		case (0x01):
		fault_count++;
		acdc_on();
		dcdc_off();
		advanced_calcs();
		ADCsampling();
		dq_control(dq_ramp,_IQ(0));
		acdc_gate_drivers();
		prev_state = 0x10;
		break;

		// AC/DC on
		case(0x11):
		advanced_calcs();
		ADCsampling();
		dq_control(dq_ramp,_IQ(0));
		acdc_gate_drivers();
		if (dq_ramp < dq_vdc_ref){ dq_ramp += _IQ(0.0005);}
		prev_state = 0x10;
		led_indicators(0x1);
		break;

		// DC/DC turn on to standard charge charge (0x13)
		case(0x13):
		dcdc_on();
		advanced_calcs();
		ADCsampling();
		dq_control(dq_vdc_ref,_IQ(0));
		acdc_gate_drivers();
		prev_state = 0x30;
		break;

		// reactive control (0x15)
		case(0x15):
		advanced_calcs();
		ADCsampling();
		dq_control(dq_vdc_ref,crp_charging(reactive_ref , &Q_int));
		acdc_gate_drivers();
		prev_state = 0x10;
		led_indicators(0x5);
		break;

		// DC/DC turn on to standard charging with reactive control
		case(0x17):
		dcdc_on();
		advanced_calcs();
		ADCsampling();
		dq_control(dq_vdc_ref, crp_charging(reactive_ref , &Q_int));
		acdc_gate_drivers();
		prev_state = 0x30;
		break;

		// DC/DC turn on to power charging
		case(0x19):
		dcdc_on();
		advanced_calcs();
		ADCsampling();
		dq_control(dq_vdc_ref,_IQ(0));
		acdc_gate_drivers();
		prev_state = 0x90;
		break;

		// DC/DC turn on to power charging with reactive control
		case(0x1D):
		dcdc_on();
		advanced_calcs();
		ADCsampling();
		dq_control(dq_vdc_ref , crp_charging(reactive_ref , &Q_int));
		acdc_gate_drivers();
		prev_state = 0x90;
		break;

		// DC/DC off from standard charging
		case(0x31):
		dcdc_off();
		dcdc_variable_reset();
		prev_state = 0x10;
		break;

		// standard charging
		case(0x33):
		advanced_calcs();
		ADCsampling();
		dq_control(dq_vdc_ref,_IQ(0));
		cc_charging(cc_ref);
		acdc_gate_drivers();
		dcdc_gate_drivers();
		prev_state = 0x30;
		led_indicators(0x3);
		break;

		// DC/DC turn off from standard charging and reactive control
		case(0x35):
		dcdc_off();
		dcdc_variable_reset();
		prev_state = 0x10;
		break;

		// standard charging and reactive control
		case(0x37):
		advanced_calcs();
		ADCsampling();
		dq_control(dq_vdc_ref , crp_charging(reactive_ref , &Q_int));
		cc_charging(cc_ref);
		acdc_gate_drivers();
		dcdc_gate_drivers();
		prev_state = 0x30;
		led_indicators(0x7);
		break;

		// switch from power charging to standard charging
		case(0x39):
		prev_state = 0x90;
		break;

		// switch from standard charging with reactive control to power charging with reactive control
		case(0x3D):
		prev_state = 0x90;
		break;

		// DC/DC off from power charging
		case(0x91):
		dcdc_off();
		dcdc_variable_reset();
		prev_state = 0x10;
		break;

		// switch from power charging to standard charging
		case(0x93):
		prev_state = 0x30;
		break;

		// DC/DC off from power charging with reactive control
		case(0x95):
		dcdc_off();
		dcdc_variable_reset();
		prev_state = 0x10;
		break;

		// switch from power charging with reactive control to standard charging with reactive control
		case(0x97):
		prev_state = 0x30;
		break;

		// power charging
		case(0x99):
		advanced_calcs();
		ADCsampling();
		dq_control(dq_vdc_ref , _IQ(0));
		cp_charging(power_ref);
		acdc_gate_drivers();
		dcdc_gate_drivers();
		prev_state = 0x90;
		led_indicators(0x9);
		break;

		// power charging with reactive control
		case(0x9D):
		advanced_calcs();
		ADCsampling();
		dq_control(dq_vdc_ref , crp_charging(reactive_ref , &Q_int));
		cp_charging(power_ref);
		acdc_gate_drivers();
		dcdc_gate_drivers();
		prev_state = 0x90;
		led_indicators(0xD);
		break;

		default:
		acdc_variable_reset();
		acdc_off();
		dcdc_off();
		prev_state = 0x00;
		led_indicators(0x0);
		break;

	}


	//clear interrupt flag and return	
	EPwm1Regs.ETCLR.bit.INT=1;				  // clear interrupt flag			
	PieCtrlRegs.PIEACK.all = PIEACK_GROUP3;   // Acknowledge interrupt to PIE
	return;	

}


//	S2.1 PI Controller Algorithm
// DELETED TO FREE UP SPACE
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

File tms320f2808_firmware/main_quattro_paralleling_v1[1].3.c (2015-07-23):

//#############################################################################
// FILE:   			main_quattro_paraleling_v1.1.c
// TITLE:  			main file of the quattro project for the received new control boards
// DESCRIPTION:		main file ho contents the main() and the other source
//					code and subroutines of the quattro project	
//	Parallel  v1.1  Paralleling phase. First is to re-organize the ADC routine into subroutines
//				    Second is to synchronize with the input voltage. We use (SOGI+FLL) to
//				    syncrhonize extracting the error from FLL and using it to decide the conecction point.
//				    We discover that we should avoid constants definition inside algorithms (i.e. _IQ(30)), do that in declaration area
//		      v1.2  We introduce a method to obtain the Phase angle for this syncronization part
//            v1.3  We introduce a method to obtain the amplitude of input voltage to finish the synchronization.
//
//
//AUTHORS:			YaoWei (19/6/09)
//#############################################################################
//+++++++++++++++++++++++++++++++++++++++++++++++++++++++++++++++++++++++++++++
//+++++++++  For IQmath variables debbuging  ++++++++++++++++++++++++++++++++++
//+++++++++++++++++++++++++++++++++++++++++++++++++++++++++++++++++++++++++++++
// Select the global Q value to use:
#define	GLOBAL_Q	19		// Q1 to Q29
long  GlobalQ = GLOBAL_Q;	//This variable is used by the GEL functions to

//+++++++++++++ Include ++++++++++++++++++++++++++++++++++++++++++++++++++++++
#include "DSP281x_Device.h"       	// DSP281x Header include file
#include "DSP281x_Examples.h"     	// DSP281x Examples include file
#include "IQmathLib.h"				//IQmath header
#include "DSP281x_Spi_complet.h"    

//+++++++++++++++++++++++++++++++++++++++++++++++++++++++++++++++++++++++++++++
//+++++++++++++ Declarations to include to run program ++++++++++++++++++++++++
//+++++++++++++ from internal Flash memory  +++++++++++++++++++++++++++++++++++
//+++++++++++++++++++++++++++++++++++++++++++++++++++++++++++++++++++++++++++++

/*extern unsigned int secureRamFuncs_loadstart;
extern unsigned int secureRamFuncs_loadend;
extern unsigned int secureRamFuncs_runstart;
*/

//+++++++++++++++++++++++++++++++++++++++++++++++++++++++++++++++++++++++++++++
//++++++++++ 50Hz sine generation variables +++++++++++++++++++++++++++++++++++
//+++++++++++++++++++++++++++++++++++++++++++++++++++++++++++++++++++++++++++++
Uint16 	countramp=0;			//Pointer for ramp generation of sinus reference

_iq25	frequency_iq=_IQ25(50.0);
_iq		amplitudeconstant_iq=_IQ(7.21758911); 
_iq		sin_out_iq=0;
_iq		sin_ampl_out_iq;			//Sinus real output
_iq		ampl_cnt_iq;				//Sinus amplitude constant

Uint16 	sinramp=0;				//Sinus ramp counter
Uint16	startramp=1;			//Flag that initiates sinus ramp
Uint16  count_amplitude=0;       //Amplitude caculator count

_iq		sinusamplitude_iq=0;	//For PDPINTA changing the reference voltage

_iq		sininput_iq[3]={0,0,0};
_iq		SampleTime_iq=_IQ30(0.00004);

//+++++++++++++++++++++++++++++++++++++++++++++++++++++++++++++++++++++++++++++
//++++++++++ Inverter control variables +++++++++++++++++++++++++++++++++++++++
//+++++++++++++++++++++++++++++++++++++++++++++++++++++++++++++++++++++++++++++
Uint32 	hh,hh2=0;				// General variable used to spend time in board test
char 	ADC_en=1;				// Enable ADC converter

Uint16 	DCBusvolt=360;			// Voltage level for the DC bus. 360V for 220Veff, 370V for 230Veff

Uint16	sinusamplitude=220;		// Amplitude of output voltage sinus Veff

Uint16 	vdc_aux=0;	 			// Counter to ramp of DC bus voltage
Uint16 	DCBus_aux=0;			// Auxiliary variable

_iq		DCBusconstant_iq=_IQ(7.57);	//To translate DCbus volt value to internal value for compare3
_iq		DCBus_iq=0;

Uint16	Shut_down=0;			//Inverter disconnection (turnrs down to 0V the VO and DCbus
char	shortcircuit=0;			//For shorcircuit action if PDPINTA is activated
//+++++++++++++++++++++++++++++++++++++++++++++++++++++++++++++++++++++++++++++
//+++++++++++ ADC calibration variables  ++++++++++++++++++++++++++++++++++++++
//+++++++++++++++++++++++++++++++++++++++++++++++++++++++++++++++++++++++++++++
_iq		Adc_iq[16] = {0,0,0,0,0,0,0,0,0,0,0,0,0,0,0,0};    //To store all the ADC channels in iq format

Uint16	AdcVR15=0;				//Variable to read 1.5 Vreference
Uint16	AdcVR05=0;				//Variable to read 1.5 Vreference

Uint16 	ii,pp=0;				// Auxiliary variables
Uint16	auxADC=0;
char 	buffer_full=0;			//Flag to indicate if the buffers are full, (=0, initiates calibration)
Uint32 	mean05=0;				//Average calculation of 0.5V voltage reference
Uint32  mean15=0;				//Average calculation of 0.5V voltage reference
Uint16  sogi_reset_ramp=0;      //sogi_reset ramp count


_iq		mean15_iq=0;
_iq		mean05_iq=0;

//+++++++++++++++++++++++++++++++++++++++++++++++++++++++++++++++++++++++++++++
//++++++++++++ PI control variables +++++++++++++++++++++++++++++++++++++++++++
//+++++++++++++++++++++++++++++++++++++++++++++++++++++++++++++++++++++++++++++
_iq 	VoOff_iq=_IQ(2048);				//Offset in Q19 to interact with ADC variables in  Q19

				/*** PI gains  ***/		//kp=0.05 ki=1800*0.00002
					
_iq 	kp_iq=_IQ(0.1);							//kp  PI gain for the output voltage loop
_iq 	kiT_iq=_IQ(350*0.00004);				//ki*T PI gain for the output voltage loop, (T/2 sampling period) (T=0.00004)
								//ki es la unica responsable de que llegue al regimen estacionario
								//hay que poner la minima ki para que regule
								//kp ha de ser baja para que minimice harmonicos en la zona sin carga

_iq 	y_pi_iq[2]={0,0};					//Actual sample: y_pi_iq[0]; previous sample:y_pi_iq[1]

_iq		ampl_fractional_iq=_IQ(0.05);
_iq		ampl_frac2_iq=0;

_iq		auxx[2]={0,0};
_iq 	auxx0_iq=0;
_iq 	auxx1_iq=0;
_iq 	auxx2_iq=0;
_iq 	auxx3_iq=0;
_iq 	auxx4_iq=0;
_iq 	auxx5_iq=0;
_iq 	auxx6_iq=0;
_iq 	auxx7_iq=0;
_iq 	auxx8_iq=0;
_iq 	auxx9_iq=0;
_iq 	auxx10_iq=0;
_iq 	auxx11_iq=0;
_iq 	auxx12_iq=0;
_iq 	auxx13_iq=0;
_iq 	auxx14_iq=0;
_iq 	auxx15_iq=0;
_iq 	auxx16_iq=0;
_iq 	auxx17_iq=0;
_iq 	auxx18_iq=0;
_iq 	auxx19_iq=0;

_iq 	auxx20_iq=0;
_iq 	auxx21_iq=0;
_iq 	auxx22_iq=0;
_iq 	auxx23_iq=0;


_iq 	auxx24_iq=0;
_iq 	auxx25_iq=0;
_iq 	auxx26_iq=0;
_iq 	auxx27_iq=0;
_iq 	auxx28_iq=0;

_iq		GP_iq=_IQ(4.5);              

_iq		GILvGVO_iq=_IQ(6.6659891);   
_iq		GILvGIO_iq=_IQ(0.5192375);    
_iq		GEvGIL_iq=_IQ(0.28595216);  
_iq		GEvGVO_iq=_IQ(1.906153965); 

_iq		rL_iq=_IQ(0.3);

_iq		GVH_iq=_IQ(1500);
_iq		MaxVH_iq=_IQ(1500);
_iq		MinVH_iq=_IQ(-1500);

_iq		Gainsat_iq=_IQ(0.005);				//Gainsat=T/0.001
_iq		MaxSatCurrent_iq=_IQ(10*0.018*1365);
_iq		MinSatCurrent_iq=_IQ(-10*0.018*1365);

_iq		Two_cnt_iq=_IQ30(1.999999999);
_iq		One_cnt_iq=_IQ30(1);
_iq     Quarter_cnt_iq=_IQ30(0.25);
_iq     Amplitude_cnt_iq[2]={0,0};


_iq		Ebusctn_iq=_IQ30(0.000271076);		//(1/3689) We chose a middle point between 3581(for 360V) and 3797(for 390V maximum)

Uint16	PWM_out=0;
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

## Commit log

2015-07-23 initial/final commit.
    Pushing to git so it may live forever :)
    [Avago Technologies Footprints.PcbLib, DSP280x_CodeStartBranch.obj, I2C MESSAGES.xlsx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]
2015-07-23 renaming folders
    [DSP280x_CodeStartBranch.obj, INVERTER_control.obj, main (Jordans MacBook.lan's conflicted copy 2013-12-22).obj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]
